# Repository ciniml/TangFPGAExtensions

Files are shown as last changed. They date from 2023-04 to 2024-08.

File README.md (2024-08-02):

# Extension boards for Tang series FPGA boards.

## 概要

Sipeedが製造・販売している、Tang Nano 9K, Tang Nano 20K およびTang Primer 20K向けのベースボードおよび拡張基板の設計データです。

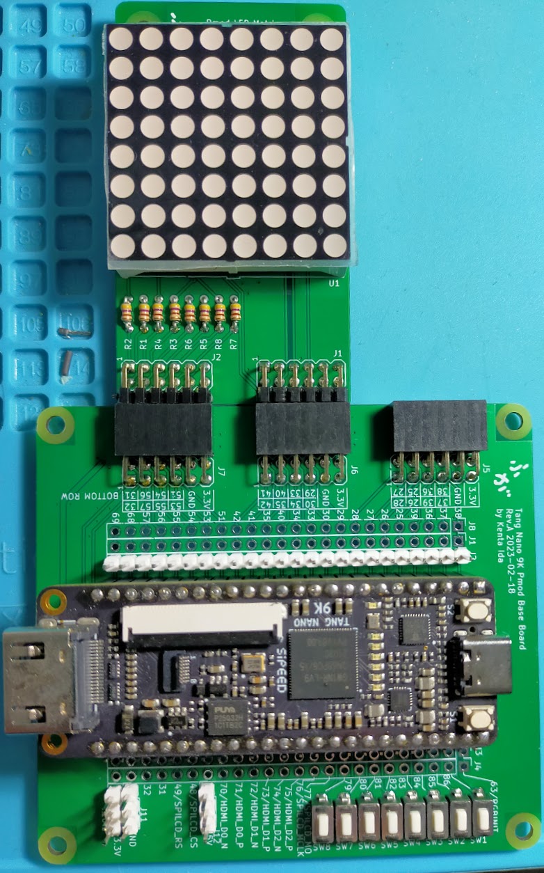
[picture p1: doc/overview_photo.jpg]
Tang Nano 9K + Matrix LED


## 内容

### 対象ボード

| 名前 | 略称  | 説明 | 購入先ページ |
| :--- | :---- | :--- | :--- |
| Tang Nano 9K | TN9K  | GW1NR-LV9搭載のボード。 | [秋月電子](https://akizukidenshi.com/catalog/g/gM-17448/) |
| Tang Primer 20K | TN20K | GW2A-LV18PG256 | [秋月電子](https://akizukidenshi.com/catalog/g/gM-17540/) |

### 基板一覧

| 名前 | 対象ボード | 説明 | KiCadプロジェクト | リビジョン |
| :--- | :--- | :--- | :--- | --- |
| [Tang Nano 9K Pmod Base Board](./README_TangNano_PmodBase.md) | TN9K | Tang Nano 9K用のPmod接続用ベースボード | [TangNano_PmodBase.kicad_pro](./TangNano_PmodBase.kicad_pro) | Rev. B |
| [Tang Primer 20K Pmod Extender ](./README_TangPrimer_PmodExtender.md) | TP20K | Tang Primer 20K用のPmod接続用拡張基板 | [TangPrimer_PmodExtender.kicad_pro](./TangPrimer_PmodExtender.kicad_pro) | Rev. B |
| [Pmod Debug Board](./README_Pmod_Debug.md) | TN9K,TP20K | Pmodのデバッグ用中継基板 | [Pmod_Debug.kicad_pro](./Pmod_Debug.kicad_pro) | Rev. A |
| Pmod HUB75 Connector Board | TN9K,TP20K | HUB75 LED Matrix接続用Pmod基板 | [Pmod_HUB75.kicad_pro](./Pmod_HUB75.kicad_pro) | Rev. A |
| Pmod LED Board | TN9K,TP20K | Pmodのデバッグ用LED基板 | [Pmod_LED.kicad_pro](./Pmod_LED.kicad_pro) | Rev. A |
| [Pmod Matrix LED](./README_Pmod_MatrixLED.md) | TN9K,TP20K | 8x8単色LEDマトリクスPmod基板 | [Pmod_MatrixLED.kicad_pro](./Pmod_MatrixLED.kicad_pro) | Rev. B |
| [Pmod MultiSegment (Single Port)](./README_Pmod_MultiSegment_SinglePort.md) | TN9K,TP20K | 6桁7+1セグメントLED Pmod基板 (シングルポート版) | [Pmod_MultiSegment_SinglePort.kicad_pro](./Pmod_MultiSegment_SinglePort.kicad_pro) | Rev. A |
| [Pmod Adapter Ethernet](./README_Pmod_Adapter_Ethernet.md) | TN9K,TP20K | LAN8720 Ethernet PHYボード用 Pmod アダプタ | [Pmod_Adapter_Ethernet.kicad_pro](./Pmod_Adapter_Ethernet.kicad_pro) | Rev. A |

## ライセンス

<br />この 作品 は <a rel="license" href="http://creativecommons.org/licenses/by/4.0/">クリエイティブ・コモンズ 表示 4.0 国際 ライセンス</a>の下に提供されています。

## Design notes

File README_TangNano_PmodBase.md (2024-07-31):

# Tang Nano 9K Pmod Base Board

## 概要

Tang Nano 9K用のPmod接続用ベースボード。Pmod 3ポート使用可能。 Pmodの信号線はすべて3.3V。 8個のタクトスイッチを実装可能 (すべて1.8V系ピン使用)

## 部品リスト

| リファレンス | 個数 | 値 | 購入元 | 備考 |
| :--- | ---- | --- | --- | --- |
| J1, J2, J3, J4, J8, J9, | 6 | 1x24 2.54mm ピンヘッダ or ピンソケット | ピンヘッダ [秋月電子](https://akizukidenshi.com/catalog/g/gC-00167/) <br/> ピンソケット [秋月電子](https://akizukidenshi.com/catalog/g/gC-05779/) | 使い方に応じてヘッダ・ソケット好きな方を実装 |
| J5, J6, J7, | 3 | 2x6 2.54mm ライトアングル ピンソケット | [秋月電子](https://akizukidenshi.com/catalog/g/gC-16795/) | |
| J10, J11, J12, | 3 | 1x3 2.54mm ピンヘッダ | ピンヘッダ [秋月電子](https://akizukidenshi.com/catalog/g/gC-00167/) | |
| R1, R2, R3, R4, R5, R6, R7, R8, | 8 | 1kΩ 1/6 | [秋月電子](https://akizukidenshi.com/catalog/g/gR-16102/) | |
| SW1, SW2, SW3, SW4, SW5, SW6, SW7, SW8, | 8 | TVBP06-B043CW-B タクトスイッチ | [秋月電子](https://akizukidenshi.com/catalog/g/gP-08074/) | |
| U1, | 2 | TangNano9K接続用ピンソケット 1x24 2.54mm ピンソケット | ピンソケット [秋月電子](https://akizukidenshi.com/catalog/g/gC-05779/) <br/> 細ピンソケット [秋月電子](https://akizukidenshi.com/catalog/g/gC-10073/) | 細にしておくとブレッドボードと共用しやすい |
| | 2 | TangNano9K接続用ピンヘッダ 1x24 2.54mm ピンヘッダ | ピンヘッダ [秋月電子](https://akizukidenshi.com/catalog/g/gC-00167/) <br/> 細ピンヘッダ [秋月電子](https://akizukidenshi.com/catalog/g/gC-06631/) | 細にしておくとブレッドボードと共用しやすい |

### 秋月買い物リスト用

秋月で部品をそろえる場合のリスト。Tang Nano 9Kに細ピンヘッダを使用、信号引き出しのピンは、ピンソケット 1列、ピンヘッダ 2列の構成

| リファレンス | 個数 | セット数 | 値 | 秋月番号 |
| :--- | ---: | ---: | --- | ---: |
| J1, J2, J3, J4, J8, J9, | 6 | 6 | 1x24 2.54mm ピンヘッダ | 100167 |
| J10, J11, J12, | 3 | 1 | 1x3 2.54mm ピンヘッダ | 100167 |
| J2, J9, | 2 | 2 | 1x24 2.54mm ピンソケット | 105779 |
| J5, J6, J7, | 3 | 3 | 2x6 2.54mm ライトアングル ピンソケット | 116795 |
| R1, R2, R3, R4, R5, R6, R7, R8, | 8 | 1 | 1kΩ 1/6 | 116102 |
| SW1, SW2, SW3, SW4, SW5, SW6, SW7, SW8, | 8 | 8 | TVBP06-B043CW-B タクトスイッチ | 108074 |
| U1, | 2 | 2 | 1x24 2.54mm 細ピンソケット | 110073 |
| | 2 | 2 | 1x24 2.54mm 細ピンヘッダ | 106631 |
| | 1 | 1 | Tang Nano 9K | 117448 |

## 回路図

回路図 (SVG)
[回路図 (PDF)](./doc/TangNano_PmodBase_Schematic.pdf)

## 外観

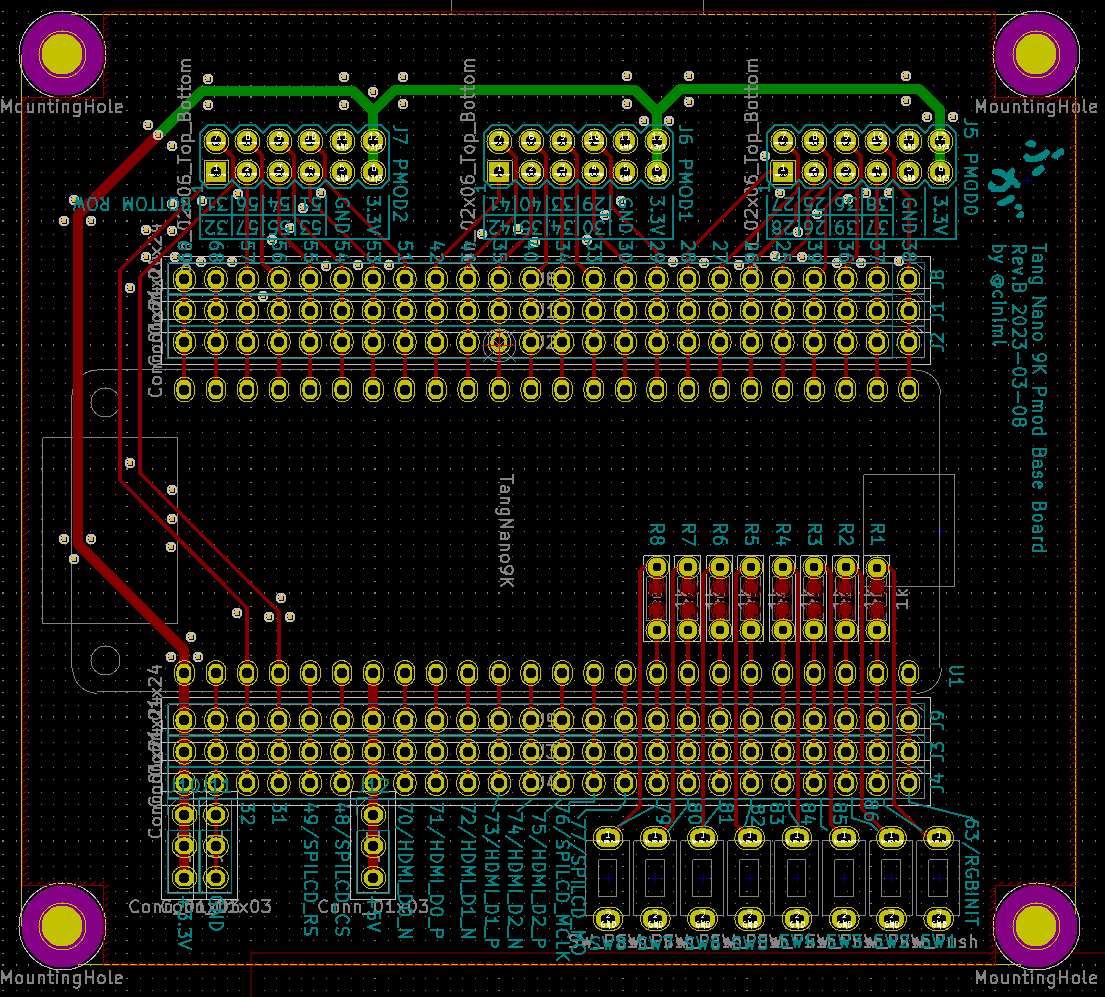
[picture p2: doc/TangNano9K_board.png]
ボード画像1


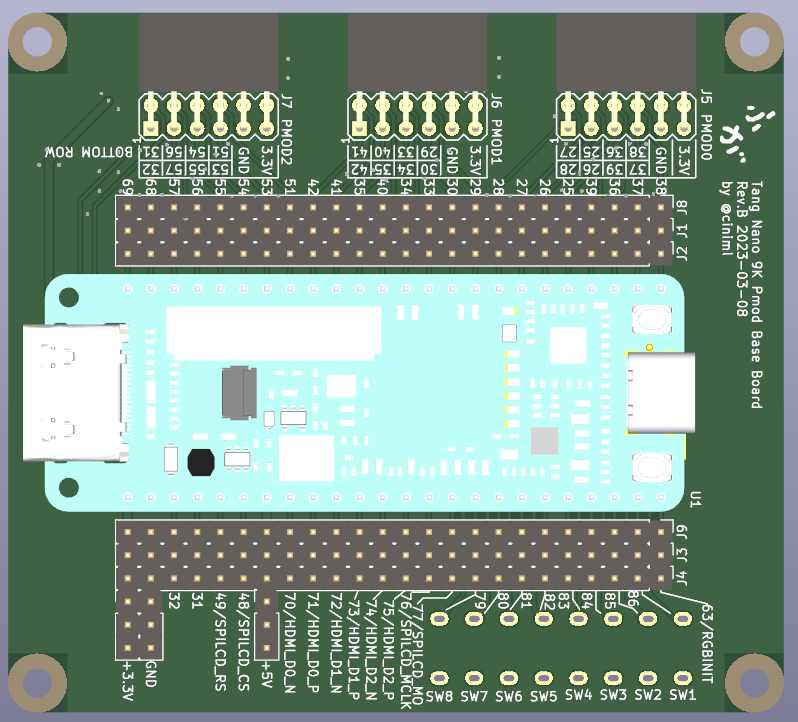
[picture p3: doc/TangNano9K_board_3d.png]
ボード画像2


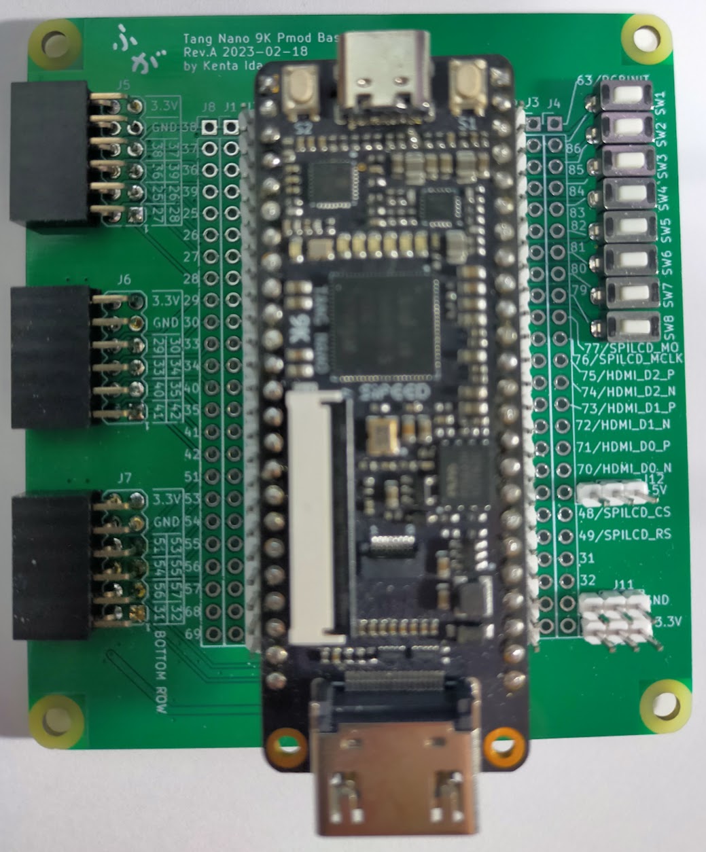
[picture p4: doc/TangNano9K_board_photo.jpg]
ボード写真


## サンプルプロジェクト

[Tang Nano 9K向けサンプル](https://github.com/ciniml/fpga_samples/tree/main/eda/cpu_matrix_led/src/tangnano9k_pmod)

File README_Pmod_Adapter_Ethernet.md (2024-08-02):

# Ethernet Pmod Adapter

## 概要

Waveshareやその他の互換ボードメーカーが販売しているMicrochip LAN8720を使ったEthernet PHYボードをPmodポートに接続するためのアダプタです。

* WaveshareのLAN8720ボード https://www.waveshare.com/lan8720-eth-board.htm
* Amazonで買える互換品 (不良品率高いので注意) https://www.amazon.co.jp/KKHMF-%E9%AB%98%E6%80%A7%E8%83%BDLAN8720%E3%82%A4%E3%83%BC%E3%82%B5%E3%83%8D%E3%83%83%E3%83%88%E3%83%9C%E3%83%BC%E3%83%8910-100%E3%82%A4%E3%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

## 部品リスト

| リファレンス | 個数 | 値 | 購入元 | 備考 |
| :--- | ---- | --- | --- | --- |
| J1 | 1 | 2x6 2.54 ライトアングル ピンヘッダ | [秋月電子](https://akizukidenshi.com/catalog/g/g116794/) | |
| J2 | 1 | 2x7 2.54mm ライトアングル ピンソケット | 2x10 ピンソケット [秋月電子](https://akizukidenshi.com/catalog/g/g105755/) | 2x7に折って使う |

### 秋月買い物リスト用

秋月で部品をそろえる場合のリスト。

| リファレンス | 個数 | セット数 | 値 | 秋月番号 |
| :--- | ---: | ---: | --- | ---: |
| J1 | 1 | 1 | ピンヘッダー L型 2×6 (12P) | 116794 |
| J2 | 3 | 1 | L型ピンソケット 2×10(20P)  | 105755 |

## 回路図

回路図 (SVG)
[回路図 (PDF)](./doc/Pmod_Adapter_Ethernet.pdf)

## 外観

ボード画像

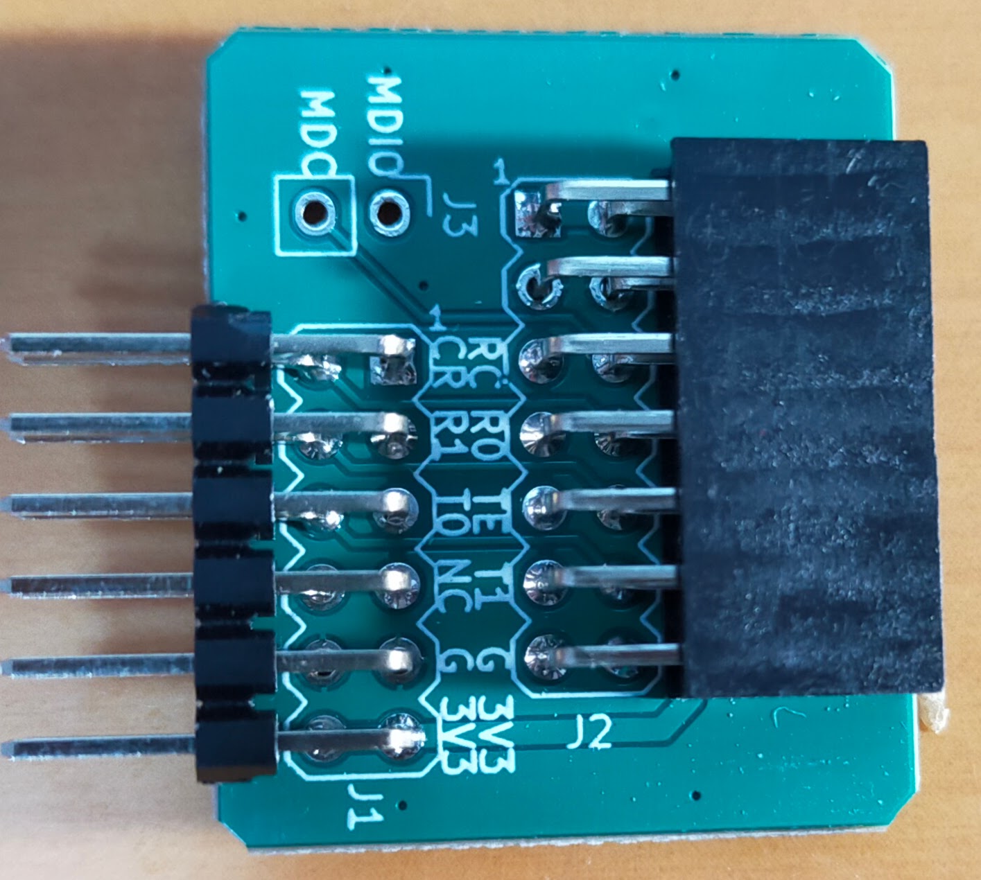
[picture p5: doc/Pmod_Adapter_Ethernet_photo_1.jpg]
ボード写真1 (単体)

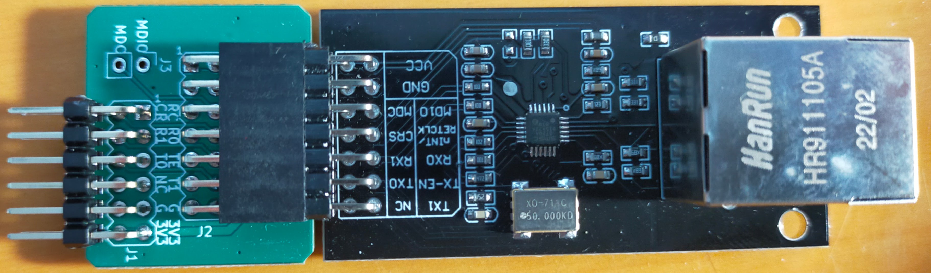
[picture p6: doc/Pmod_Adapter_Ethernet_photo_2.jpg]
ボード写真2 (LAN8720ボード接続)


## サンプルプロジェクト

[Tang Nano 9K向けサンプル](https://github.com/ciniml/fpga_samples/tree/main/eda/ethernet_icmp/src/tangnano9k_pmod)

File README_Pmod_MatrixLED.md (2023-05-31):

# Pmod Matrix LED

## 概要

秋月電子で購入可能なOptosupplyの8x8マトリクスLED OSL641501-AXA のPmodモジュールです。Pmod 2ポート使用。

## 部品リスト

| リファレンス | 個数 | 値 | 購入元 | 備考 |
| :--- | ---- | --- | --- | --- |
| J1, J2, | 2 | 2x6 2.54mm ライトアングル ピンヘッダ | [秋月電子](https://akizukidenshi.com/catalog/g/gC-00148/) | 2x6で分割する |
| R1, R2, R3, R4, R5, R6, R7, R8, | 8 | 470Ω 1/6W | [秋月電子](https://akizukidenshi.com/catalog/g/gR-16471/) | |
| U1, | 1 | OSL641501-ARA | [秋月電子](OSL641501-AXA) | |

## 回路図

回路図 (SVG)
[回路図 (PDF)](./doc/Pmod_MatrixLED_Schematic.pdf)

## 外観

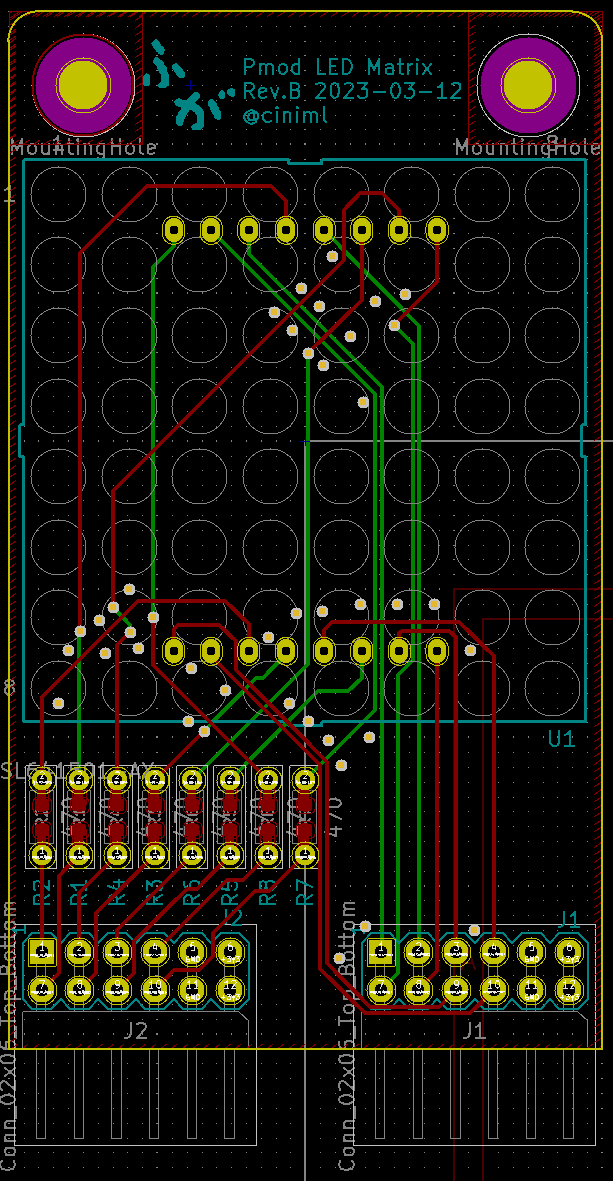
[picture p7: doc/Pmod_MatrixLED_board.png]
ボード画像1


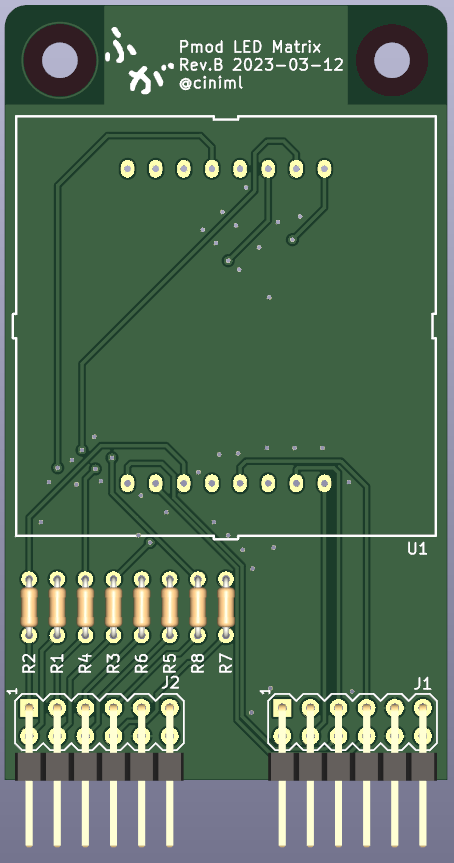
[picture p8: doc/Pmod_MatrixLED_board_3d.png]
ボード画像2


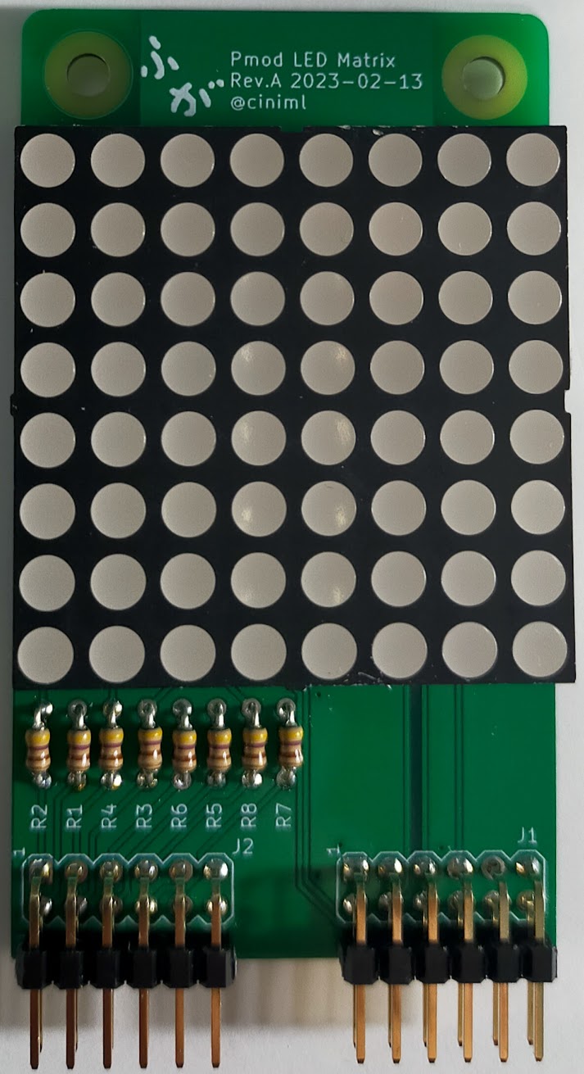
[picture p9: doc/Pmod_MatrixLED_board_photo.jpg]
ボード写真


## サンプルプロジェクト

[Tang Nano 9K向けサンプル](https://github.com/ciniml/fpga_samples/tree/main/eda/cpu_matrix_led/src/tangnano9k_pmod)

[Tang Primer 20K向けサンプル](https://github.com/ciniml/fpga_samples/tree/main/eda/cpu_matrix_led/src/tangnano9k_pmod)

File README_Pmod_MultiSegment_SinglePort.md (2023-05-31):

# Pmod MultieSegment (Single Port版)

## 概要

秋月電子で購入可能なOptosupplyの6桁 7+1セグメントLED [OSL60362-LR](https://akizukidenshi.com/catalog/g/gI-17987/) のPmodモジュールです。
単純に接続した場合は2ポート必要になりますが、8bitシフトレジスタを使って桁選択とセグメント出力をそれぞれ4線で制御し、Pmod 1ポートに収めています。
FPGA側の制御回路は少し複雑になりますが、Pmodポートを他につかうことができます。

## 部品リスト

| リファレンス | 個数 | 値 | 購入元 | 備考 |
| :--- | ---- | --- | --- | --- |
| J1, | 1 | 2x6 2.54mm ライトアングル ピンヘッダ | [秋月電子](https://akizukidenshi.com/catalog/g/gC-00148/) | 2x6で分割する |
| R1, R2, R3, R4, R5, R6, | 6 | 470Ω 1/6W | [秋月電子](https://akizukidenshi.com/catalog/g/gR-16471/) | |
| U2, | 1 | OSL60362-LX | [秋月電子](https://akizukidenshi.com/catalog/g/gI-17987/) | カソードコモンタイプを使う | |
| U1, U3 | 2 | TC74HC595AF | [秋月電子](https://akizukidenshi.com/catalog/g/gI-10077/) |  | |

## 回路図

回路図 (SVG)
[回路図 (PDF)](./doc/Pmod_MultiSegment_SinglePort.pdf)

## 外観

準備中

## サンプルプロジェクト

準備中

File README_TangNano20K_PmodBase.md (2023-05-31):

# Tang Nano 20K Pmod Base Board

## 概要

Tang Nano 20K用のPmod接続用ベースボード。Pmod 3ポート使用可能。 Pmodの信号線はすべて3.3V。 8個のタクトスイッチを実装可能

## 部品リスト

| リファレンス | 個数 | 値 | 購入元 | 備考 |
| :--- | ---- | --- | --- | --- |
| J1, J2, J3, J4, J8, J9, | 6 | 1x24 2.54mm ピンヘッダ or ピンソケット | ピンヘッダ [秋月電子](https://akizukidenshi.com/catalog/g/gC-00167/) <br/> ピンソケット [秋月電子](https://akizukidenshi.com/catalog/g/gC-05779/) | 使い方に応じてヘッダ・ソケット好きな方を実装 |
| J5, J6, J7, | 3 | 2x6 2.54mm ライトアングル ピンソケット | [秋月電子](https://akizukidenshi.com/catalog/g/gC-16795/) | |
| J10, J11, J12, | 3 | 1x3 2.54mm ピンヘッダ | ピンヘッダ [秋月電子](https://akizukidenshi.com/catalog/g/gC-00167/) | |
| R1, R2, R3, R4, R5, R6, R7, R8, | 8 | 1kΩ 1/6 | [秋月電子](https://akizukidenshi.com/catalog/g/gR-16102/) | |
| SW1, SW2, SW3, SW4, SW5, SW6, SW7, SW8, | 8 | TVBP06-B043CW-B タクトスイッチ | [秋月電子](https://akizukidenshi.com/catalog/g/gP-08074/) | |
| U1, | 2 | TangNano9K接続用ピンソケット 1x20 2.54mm ピンソケット | ピンソケット [秋月電子](https://akizukidenshi.com/catalog/g/gC-05779/) <br/> 細ピンソケット [秋月電子](https://akizukidenshi.com/catalog/g/gC-10073/) | 細にしておくとブレッドボードと共用しやすい |
| | 2 | TangNano9K接続用ピンヘッダ 1x20 2.54mm ピンヘッダ | ピンヘッダ [秋月電子](https://akizukidenshi.com/catalog/g/gC-00167/) <br/> 細ピンヘッダ [秋月電子](https://akizukidenshi.com/catalog/g/gC-06631/) | 細にしておくとブレッドボードと共用しやすい |

## 回路図

回路図 (SVG)
[回路図 (PDF)](./doc/TangNano20K_PmodBase_Schematic.pdf)

## 外観

基板レイアウト(表)
基板レイアウト(裏)

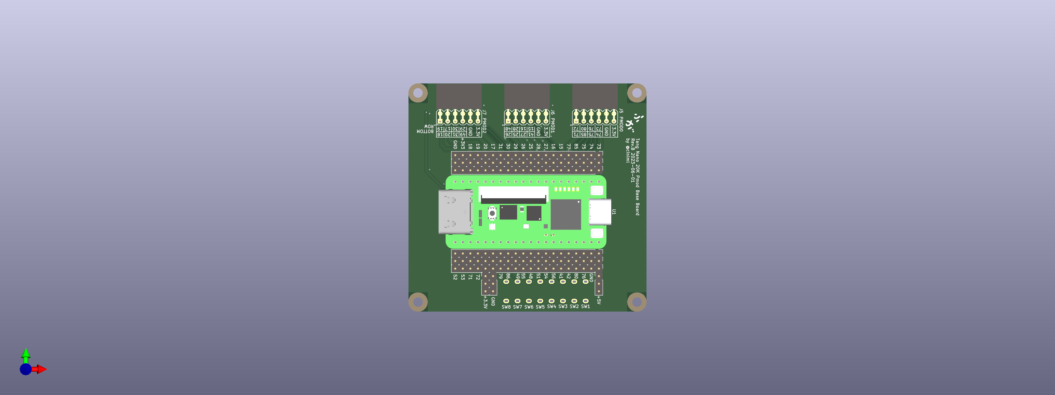
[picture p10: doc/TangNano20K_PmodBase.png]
ボード画像


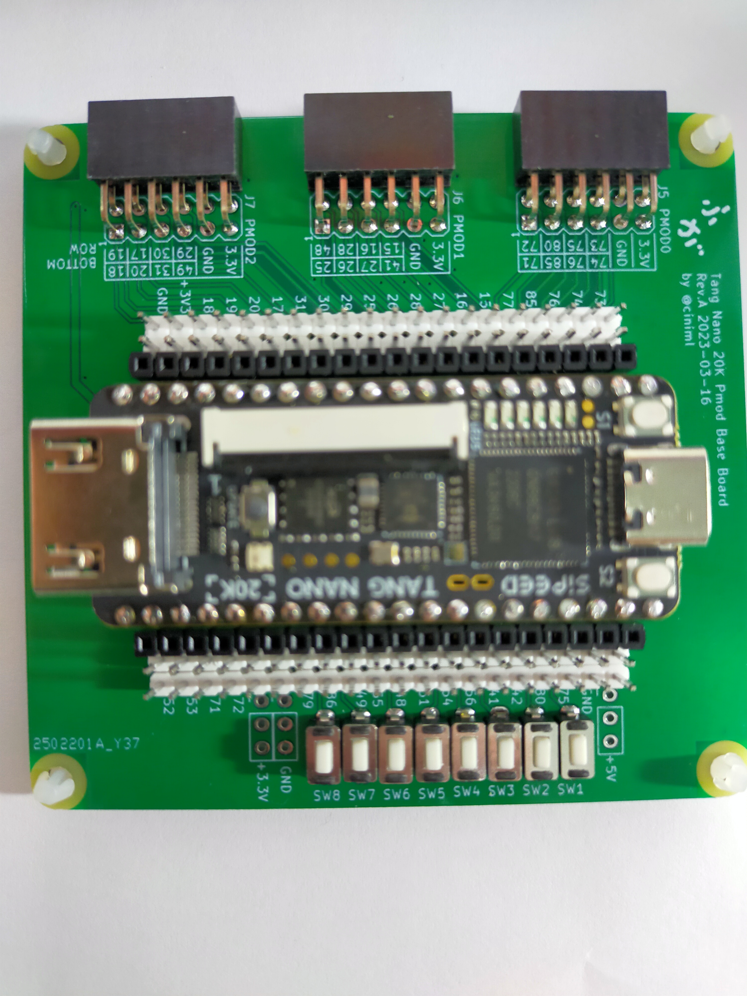
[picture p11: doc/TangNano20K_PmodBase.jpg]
ボード写真


## サンプルプロジェクト

[Tang Nano 20K向けサンプル](https://github.com/ciniml/fpga_samples/tree/main/eda/cpu_matrix_led/src/tangnano20k)

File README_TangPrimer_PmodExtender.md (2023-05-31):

# Tang Primer 20K Pmod Extender

## 概要

Tang Primer 20K用のPmod接続用拡張ボード。

Tang Primer 20KにはもともとPmod相当のポートが4つついているが、Pmod規格が定める形状の制約を満たしておらず、Pmod規格ボードを接続することが難しい。
Tang Primer 20K Pmod ExtenderはTang Primer 20KのPmod相当ポート4つに接続し、各ポートをPmod規格が定める向きおよび配置に変換します。

## 部品リスト

| リファレンス | 個数 | 値 | 購入元 | 備考 |
| :--- | ---- | --- | --- | ---- |
| J1, J2, J3, J4, | 4 | 2x6 2.54mm ピンヘッダ | ピンヘッダ [秋月電子](https://akizukidenshi.com/catalog/g/gC-00167/) | |
| J5, J6, J7, J8, | 4 | 2x6 2.54mm ライトアングル ピンソケット | [秋月電子](https://akizukidenshi.com/catalog/g/gC-16795/) | |

## 回路図

回路図 (SVG)
[回路図 (PDF)](./doc/TangPrimer_PmodExtender_Schematic.pdf)

## 外観

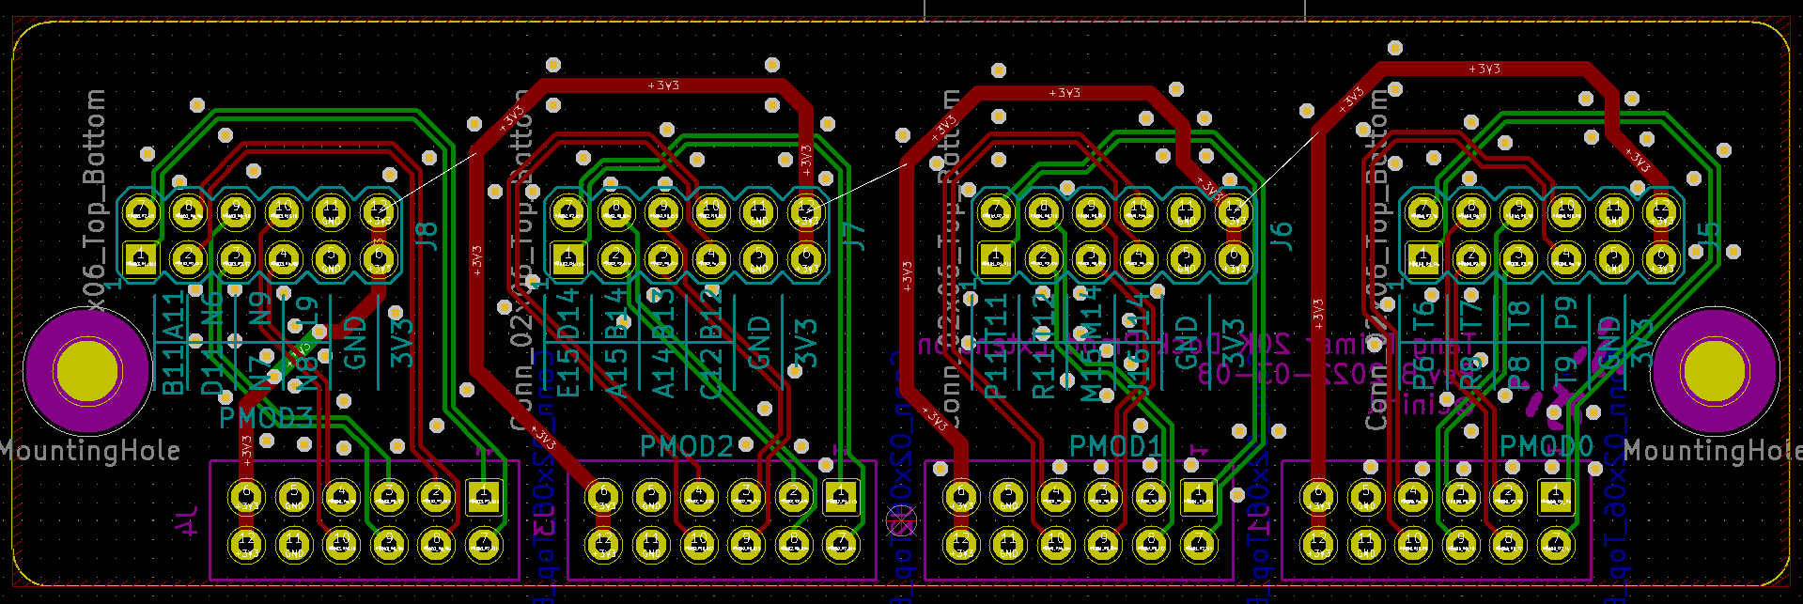
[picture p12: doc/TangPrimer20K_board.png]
ボード画像1


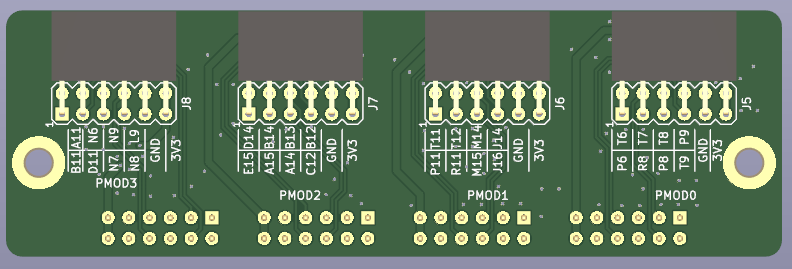
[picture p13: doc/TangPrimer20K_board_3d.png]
ボード画像2


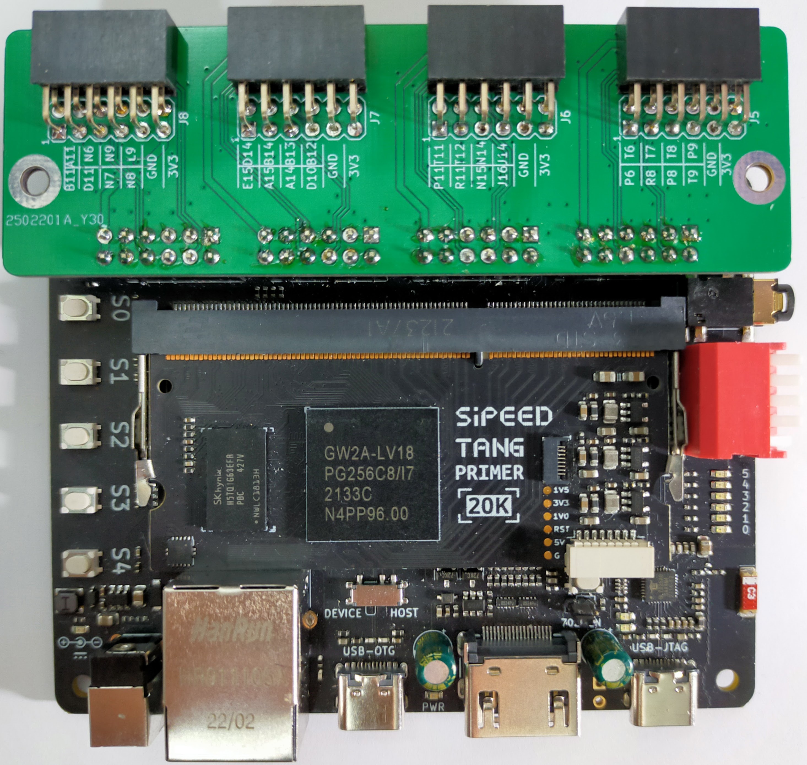
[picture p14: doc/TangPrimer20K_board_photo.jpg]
ボード写真


## サンプルプロジェクト

[Tang Primer 20K向けサンプル](https://github.com/ciniml/fpga_samples/tree/main/eda/cpu_matrix_led/src/tangprimer20k)

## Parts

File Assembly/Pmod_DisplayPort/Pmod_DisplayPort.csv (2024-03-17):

Designator | Comment | Footprint | MPN | JLCPCB Part #
C1 | 100n | Capacitor_SMD:C_0402_1005Metric | CL05B104KB54PNC | C307331
C2 | 100n | Capacitor_SMD:C_0402_1005Metric | CL05B104KB54PNC | C307331
C3 | 100n | Capacitor_SMD:C_0402_1005Metric | CL05B104KB54PNC | C307331
C4 | 100n | Capacitor_SMD:C_0402_1005Metric | CL05B104KB54PNC | C307331
C5 | 100n | Capacitor_SMD:C_0402_1005Metric | CL05B104KB54PNC | C307331
C6 | 100n | Capacitor_SMD:C_0402_1005Metric | CL05B104KB54PNC | C307331
C7 | 100n | Capacitor_SMD:C_0402_1005Metric | CL05B104KB54PNC | C307331
C8 | 100n | Capacitor_SMD:C_0402_1005Metric | CL05B104KB54PNC | C307331
C9 | 100n | Capacitor_SMD:C_0402_1005Metric | CL05B104KB54PNC | C307331
C10 | 100n | Capacitor_SMD:C_0402_1005Metric | CL05B104KB54PNC | C307331
CN1 | HYC16-DP20-178 | local:DisplayPort_HOAUC-HYC16-DP20-178 | HYC16-DP20-178 | C711350
R1 | 100k | Resistor_SMD:R_0402_1005Metric | 0402WGF1003TCE | C25741
R2 | 100k | Resistor_SMD:R_0402_1005Metric | 0402WGF1003TCE | C25741
R3 | 49.9 | Resistor_SMD:R_0402_1005Metric | 0402WGF499JTCE | C25120
R4 | 49.9 | Resistor_SMD:R_0402_1005Metric | 0402WGF499JTCE | C25120
R5 | 49.9 | Resistor_SMD:R_0402_1005Metric | 0402WGF499JTCE | C25120
R6 | 49.9 | Resistor_SMD:R_0402_1005Metric | 0402WGF499JTCE | C25120
R7 | 49.9 | Resistor_SMD:R_0402_1005Metric | 0402WGF499JTCE | C25120
R8 | 49.9 | Resistor_SMD:R_0402_1005Metric | 0402WGF499JTCE | C25120
R9 | 49.9 | Resistor_SMD:R_0402_1005Metric | 0402WGF499JTCE | C25120
R10 | 49.9 | Resistor_SMD:R_0402_1005Metric | 0402WGF499JTCE | C25120
R11 | 49.9 | Resistor_SMD:R_0402_1005Metric | 0402WGF499JTCE | C25120
R12 | 49.9 | Resistor_SMD:R_0402_1005Metric | 0402WGF499JTCE | C25120
R13 | 100k | Resistor_SMD:R_0402_1005Metric | 0402WGF1003TCE | C25741
R14 | 10k | Resistor_SMD:R_0402_1005Metric | 0402WGF1002TCE | C25744

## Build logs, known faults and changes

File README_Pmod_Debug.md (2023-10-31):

# Pmod Debug 中継基板

## 概要

PmodモジュールとPmod対応ボードの間に挿入して、Pmodの信号線をロジック・アナライザ等で観測しやすくするための中継基板です。

## 部品リスト

| リファレンス | 個数 | 値 | 購入元 | 備考 |
| :--- | ---- | --- | --- | --- |
| J1, | 1 | 2x6 2.54mm ライトアングル ピンヘッダ | [秋月電子](https://akizukidenshi.com/catalog/g/gC-00148/) | 2x6で分割する |
| J2, | 1 | 2x6 2.54mm ピンヘッダ | [秋月電子](https://akizukidenshi.com/catalog/g/gC-00167/) | 2x6で分割する |
| J3, | 1 | 2x6 2.54mm ライトアングル ピンソケット | [秋月電子](https://akizukidenshi.com/catalog/g/gC-16795/) | 2x6で分割する |

## 回路図

回路図 (SVG)
[回路図 (PDF)](./doc/Pmod_Debug.pdf)

## 外観

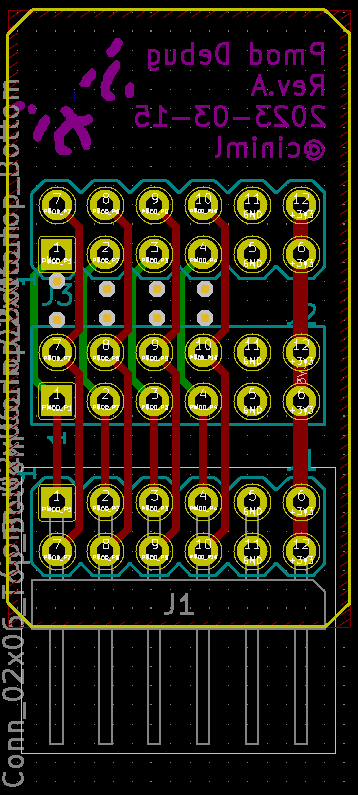
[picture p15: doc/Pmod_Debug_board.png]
ボード画像1


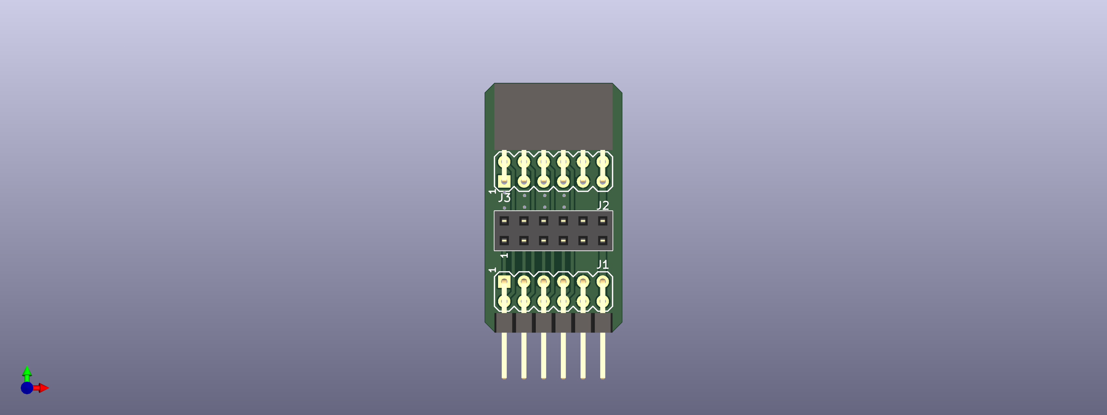
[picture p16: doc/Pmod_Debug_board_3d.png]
ボード画像2


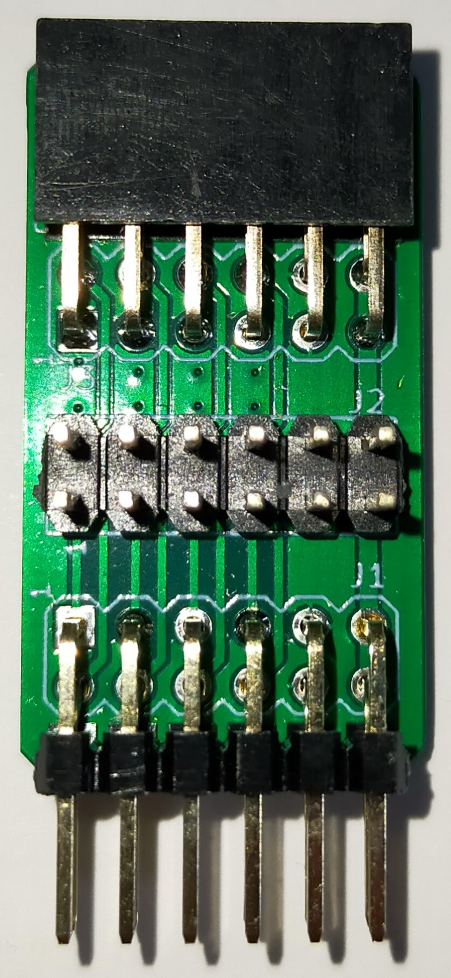
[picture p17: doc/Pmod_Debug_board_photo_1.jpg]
ボード写真1


ボード写真2

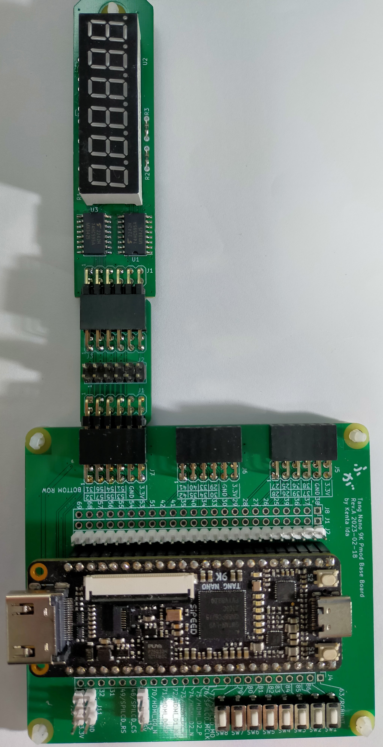
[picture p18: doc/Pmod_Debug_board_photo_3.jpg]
ボード写真3


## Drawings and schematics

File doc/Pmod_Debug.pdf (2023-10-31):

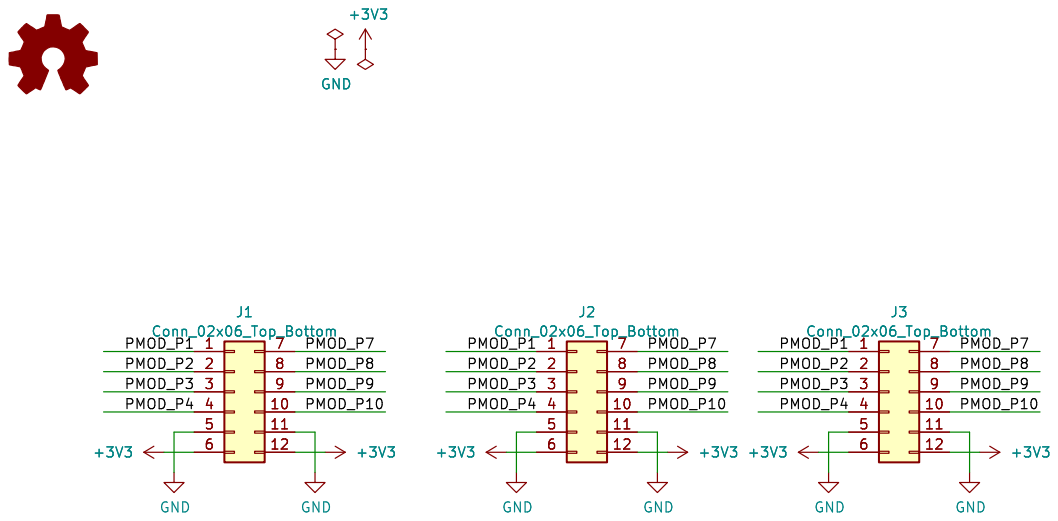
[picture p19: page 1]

Id: 1/1 Title: Pmod Matrix LED module

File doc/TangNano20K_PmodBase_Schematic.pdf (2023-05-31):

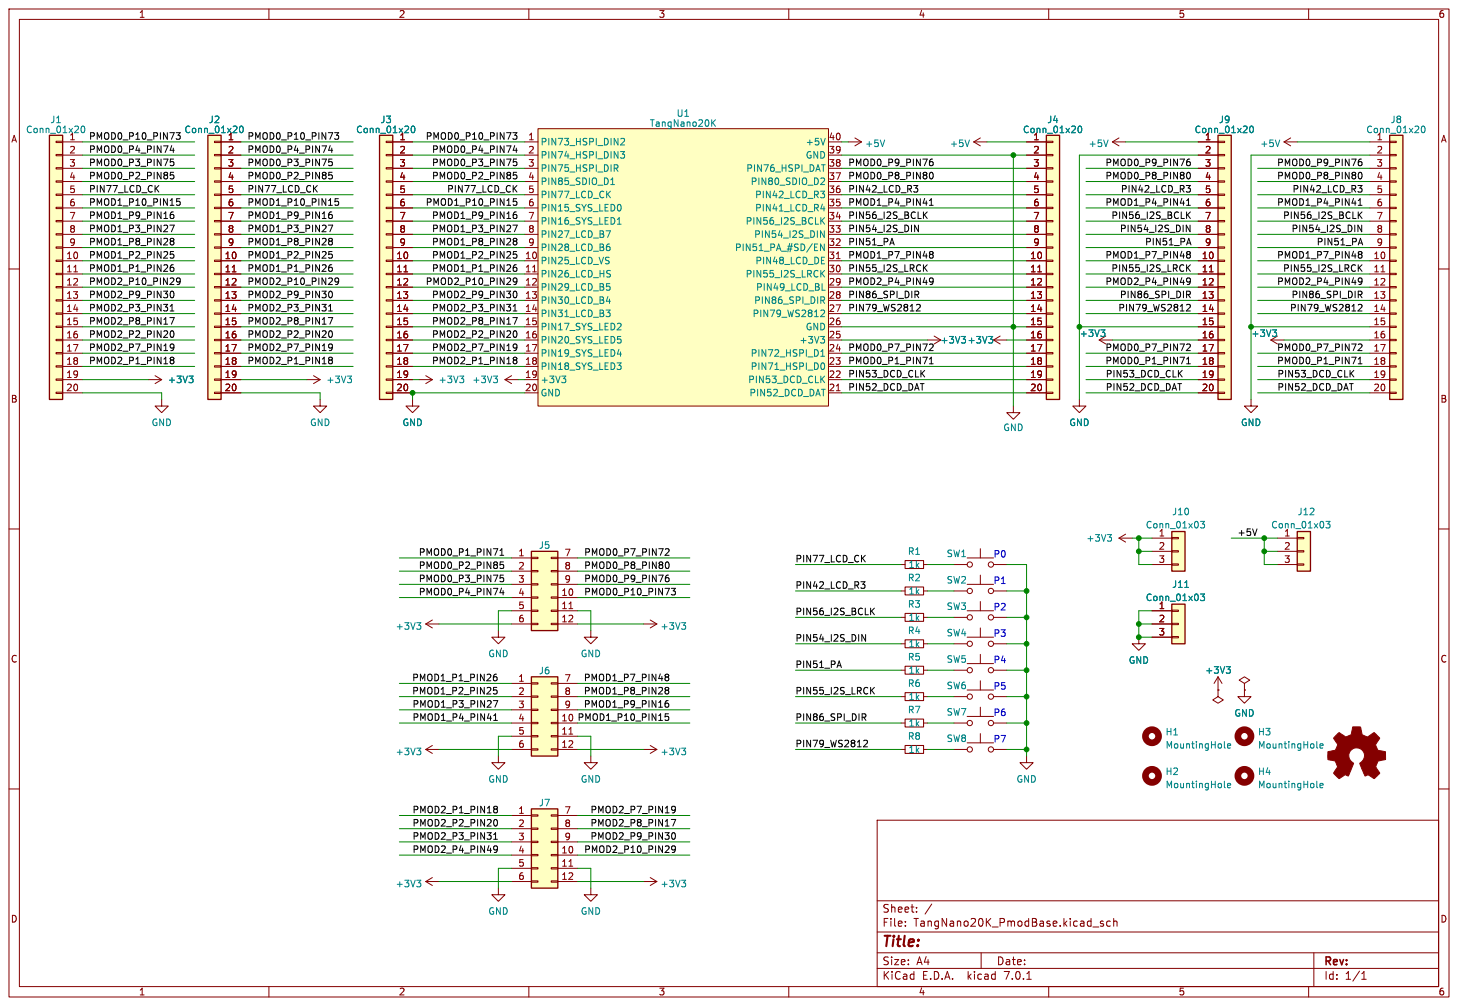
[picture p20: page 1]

Id: 1/1 Title: File: TangNano20K_PmodBase.kicad_sch Sheet: /

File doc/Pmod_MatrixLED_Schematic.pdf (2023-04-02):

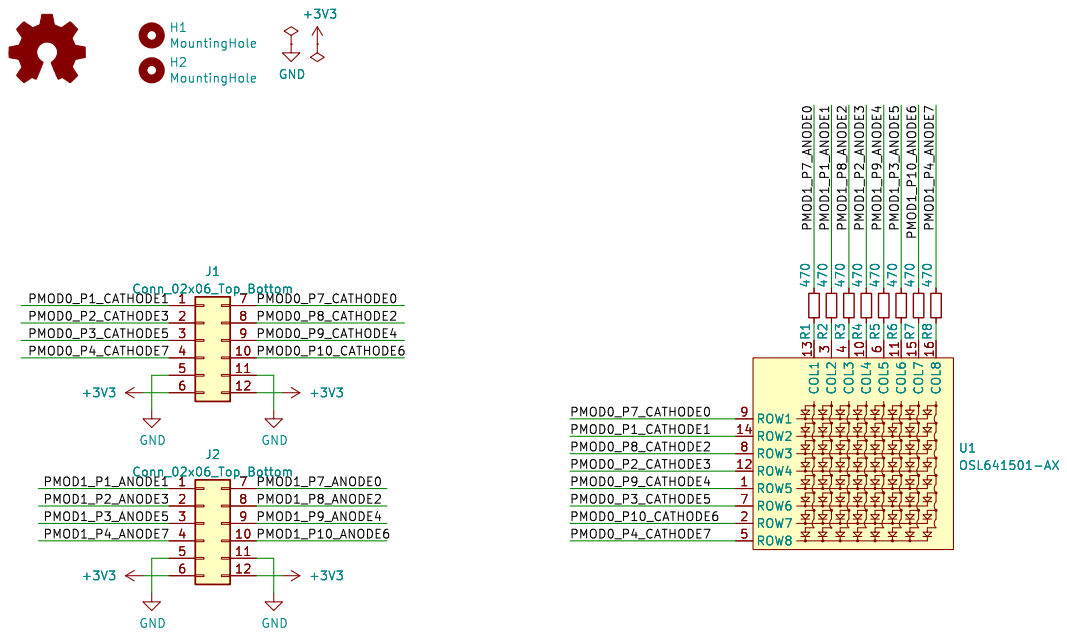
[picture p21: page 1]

Id: 1/1 Title: Pmod Matrix LED module

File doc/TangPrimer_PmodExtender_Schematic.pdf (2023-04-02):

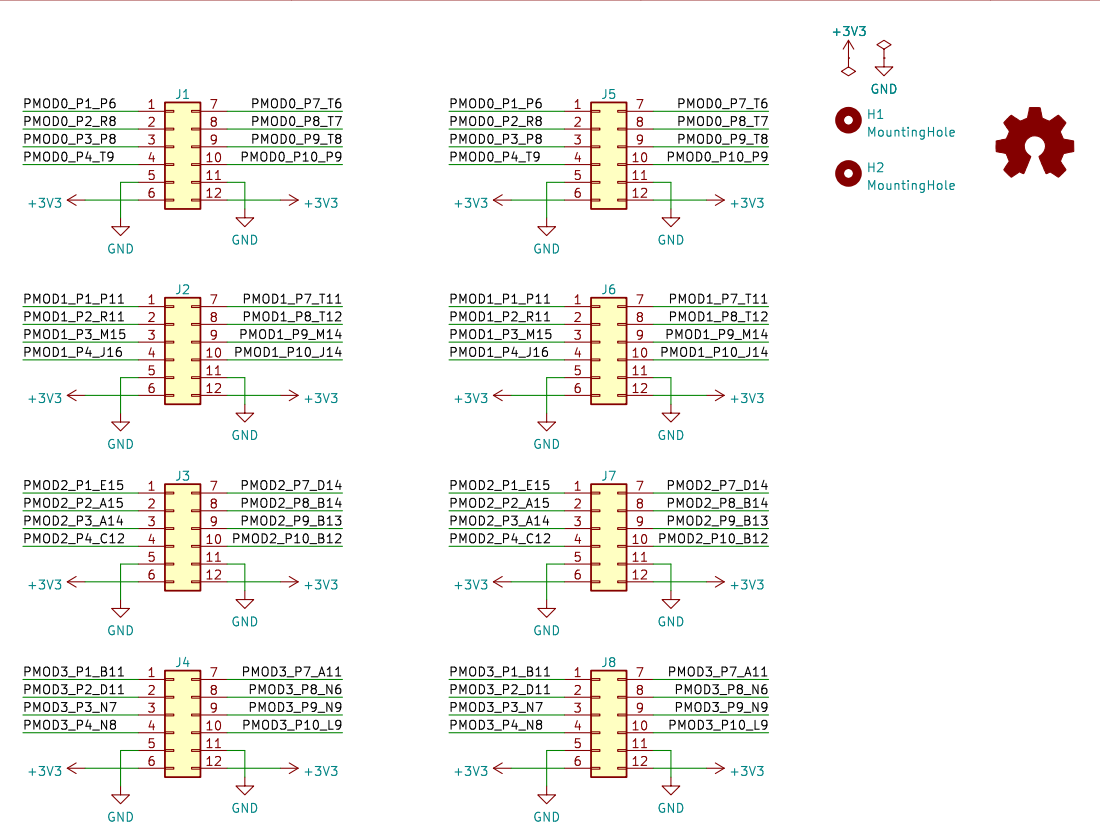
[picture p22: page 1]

Id: 1/1 Title: Tang Primer 20K Pmod Extender File: TangPrimer_PmodExtender.kicad_sch Sheet: /

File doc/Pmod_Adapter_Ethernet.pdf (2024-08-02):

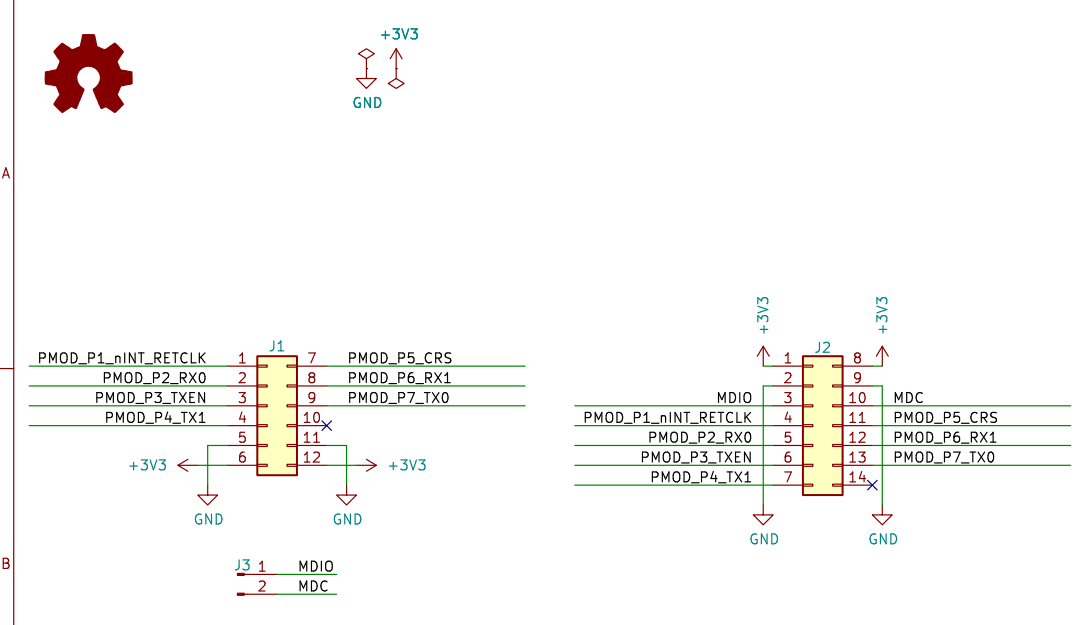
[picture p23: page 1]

Id: 1/1 Title: Pmod Matrix LED module

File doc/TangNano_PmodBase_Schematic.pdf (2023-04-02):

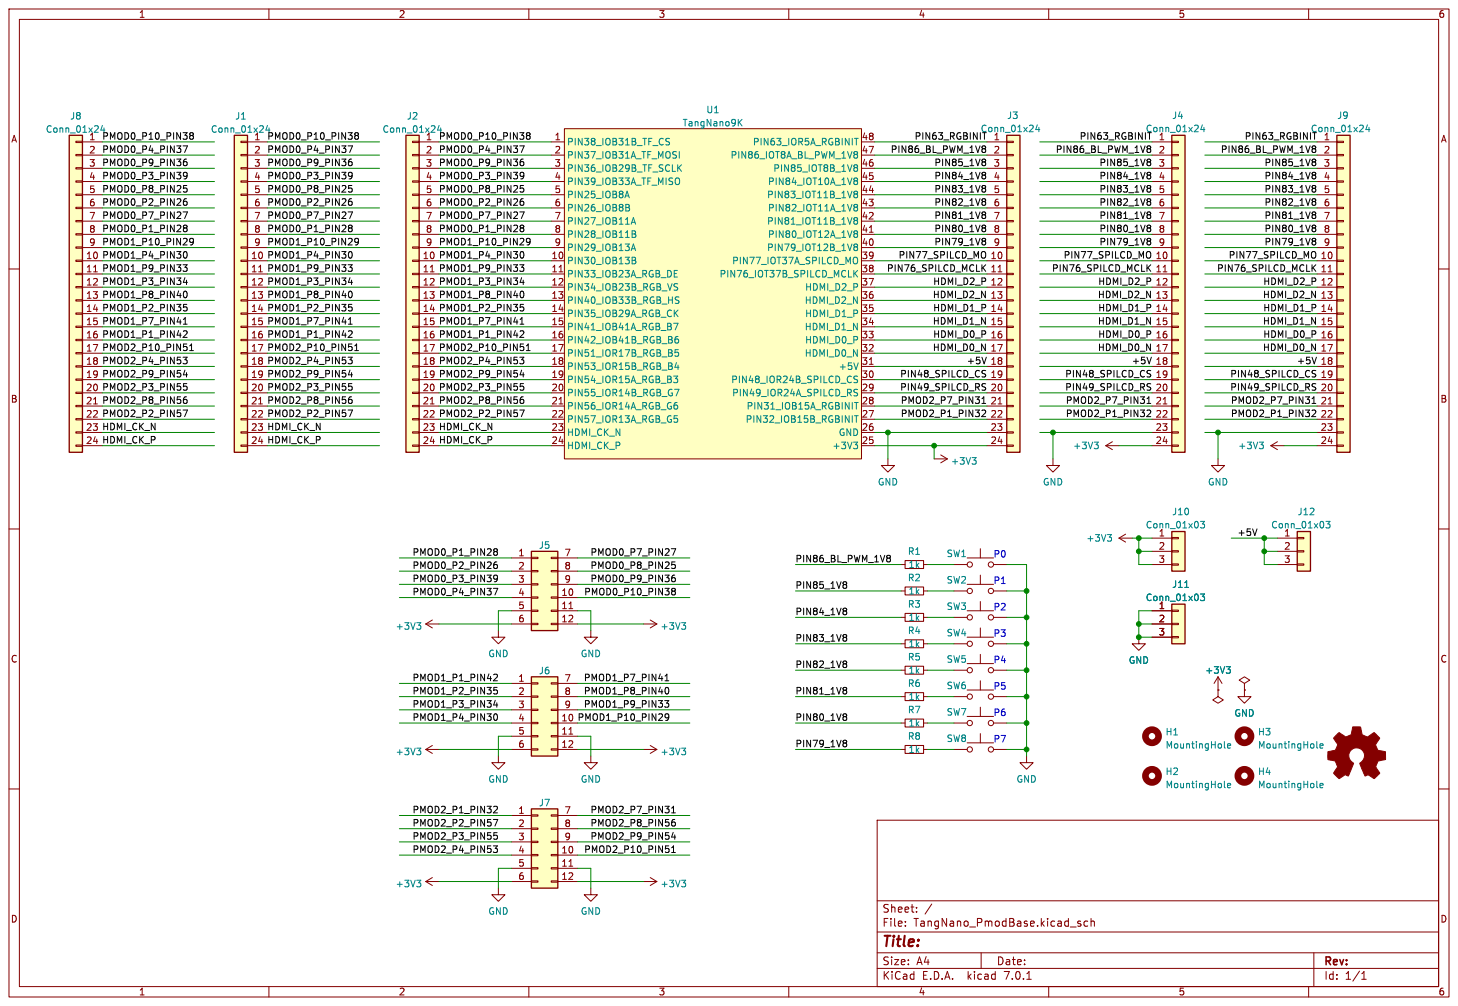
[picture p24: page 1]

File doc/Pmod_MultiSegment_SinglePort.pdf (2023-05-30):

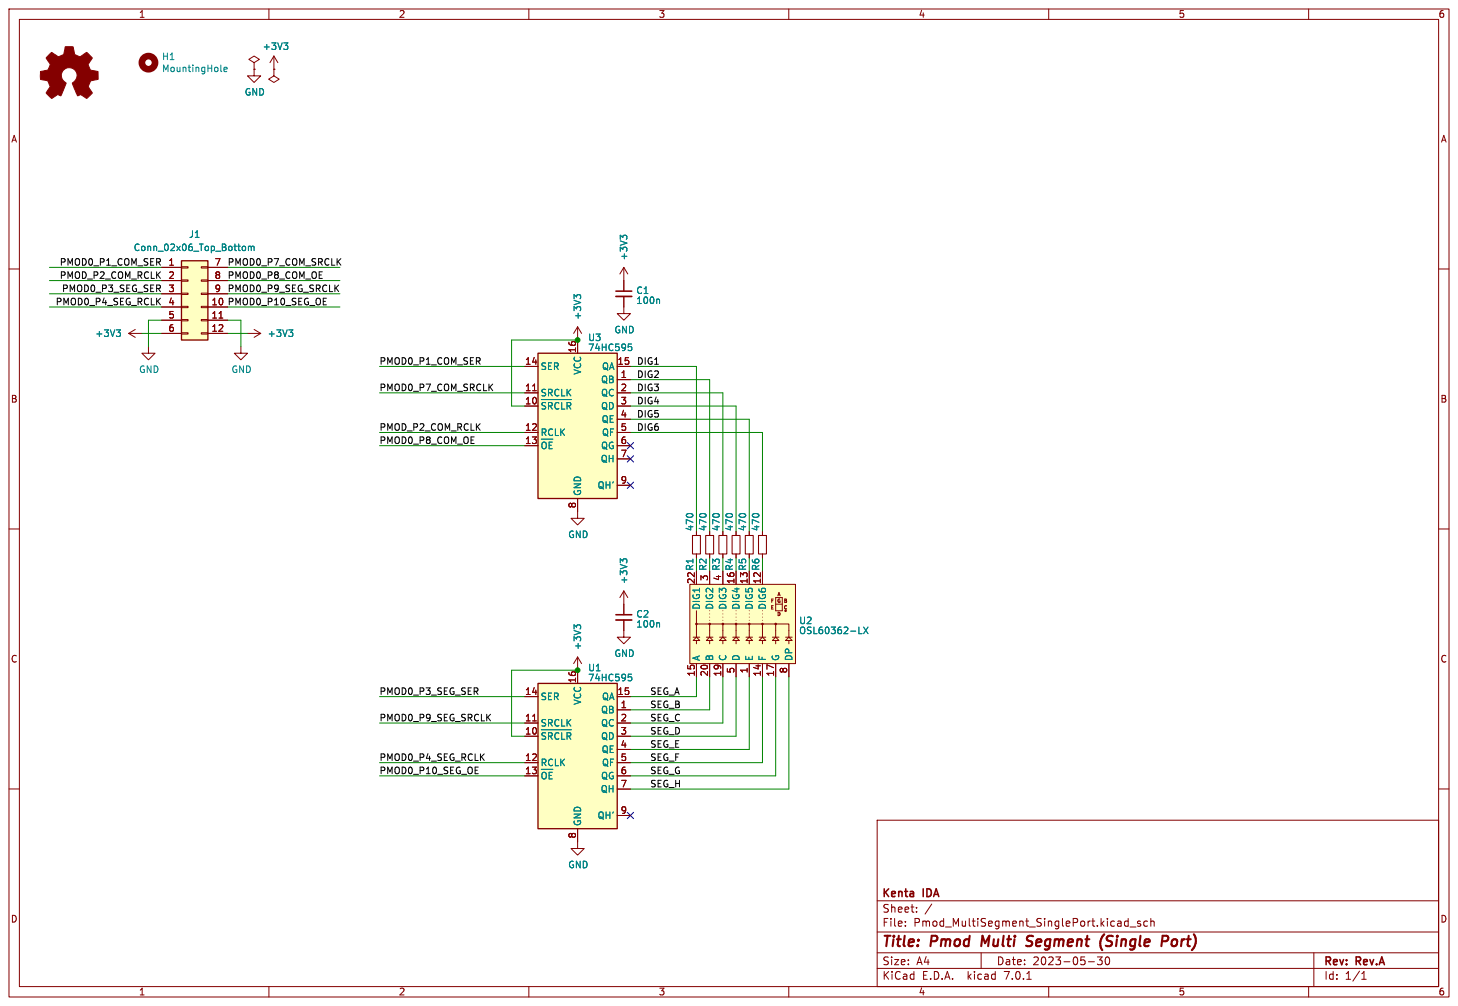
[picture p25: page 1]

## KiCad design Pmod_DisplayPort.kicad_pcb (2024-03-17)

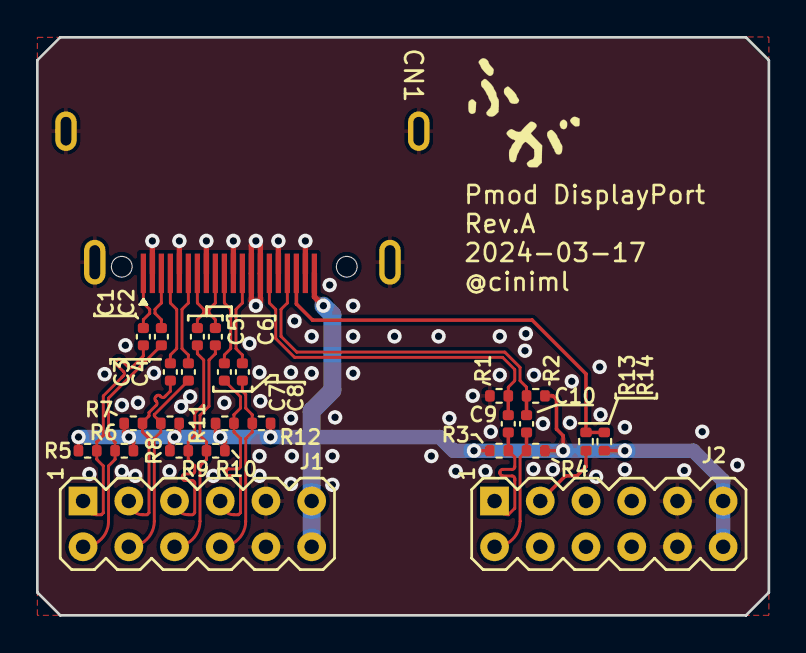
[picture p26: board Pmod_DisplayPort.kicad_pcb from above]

Board: 2 copper layers, 40.6 x 32.1 mm, 28 parts (0 on the bottom side), 24 nets.

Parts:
C1, C2, C3, C4, C5, C6, C7, C8, C9, C10: 100n; C_0402_1005Metric
CN1: DisplayPort_DP-GD-120PWB
J1, J2: Conn_02x06_Top_Bottom; Conn_Pmod_Spec_B_Thin
LOGO1: Logo_Open_Hardware_Small; logo
R1, R2, R13: 100k; R_0402_1005Metric
R3, R4, R5, R6, R7, R8, R9, R10, R11, R12: 50; R_0402_1005Metric
R14: 10k; R_0402_1005Metric

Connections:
+3V3: CN1.20 (DP_PWR), J1.6, J1.12, J2.6, J2.12, R2.1, R3.1, R4.1, R5.1, R6.1, R7.1, R8.1, R9.1, R10.1, R11.1, R12.1, R13.1
/AUX_N: C10.2, CN1.17 (AUX_CH_N), R2.2
/AUX_P: C9.2, CN1.15 (AUX_CH_P), R1.2
/HPD: CN1.18 (HOT_PLUG), R13.2, R14.1
/ML0_N: C2.2, CN1.3 (ML_LANE0_N)
/ML0_P: C1.2, CN1.1 (ML_LANE0_P)
/ML1_N: C4.2, CN1.6 (ML_LANE1_N)
/ML1_P: C3.2, CN1.4 (ML_LANE1_P)
/ML2_N: C6.2, CN1.9 (ML_LANE2_N)
/ML2_P: C5.2, CN1.7 (ML_LANE2_P)
/ML3_N: C8.2, CN1.12 (ML_LANE3_N)
/ML3_P: C7.2, CN1.10 (ML_LANE3_P)
/PMOD_AUX_CH_N: C10.1, J2.7, R4.2
/PMOD_AUX_CH_P: C9.1, J2.1, R3.2
/PMOD_L0_N: C2.1, J1.7, R6.2
/PMOD_L0_P: C1.1, J1.1, R5.2
/PMOD_L1_N: C4.1, J1.8, R8.2
/PMOD_L1_P: C3.1, J1.2, R7.2
/PMOD_L2_N: C6.1, J1.9, R10.2
/PMOD_L2_P: C5.1, J1.3, R9.2
/PMOD_L3_N: C8.1, J1.10, R12.2
/PMOD_L3_P: C7.1, J1.4, R11.2
/PMOD_P2_HOT_PLUG: J2.2, R14.2
GND: CN1.2 (GND), CN1.5 (GND), CN1.8 (GND), CN1.11 (GND), CN1.13 (CONFIG1), CN1.14 (CONFIG2), CN1.16 (GND), CN1.19 (Return), CN1.FG, J1.5, J1.11, J2.5, J2.11, R1.1

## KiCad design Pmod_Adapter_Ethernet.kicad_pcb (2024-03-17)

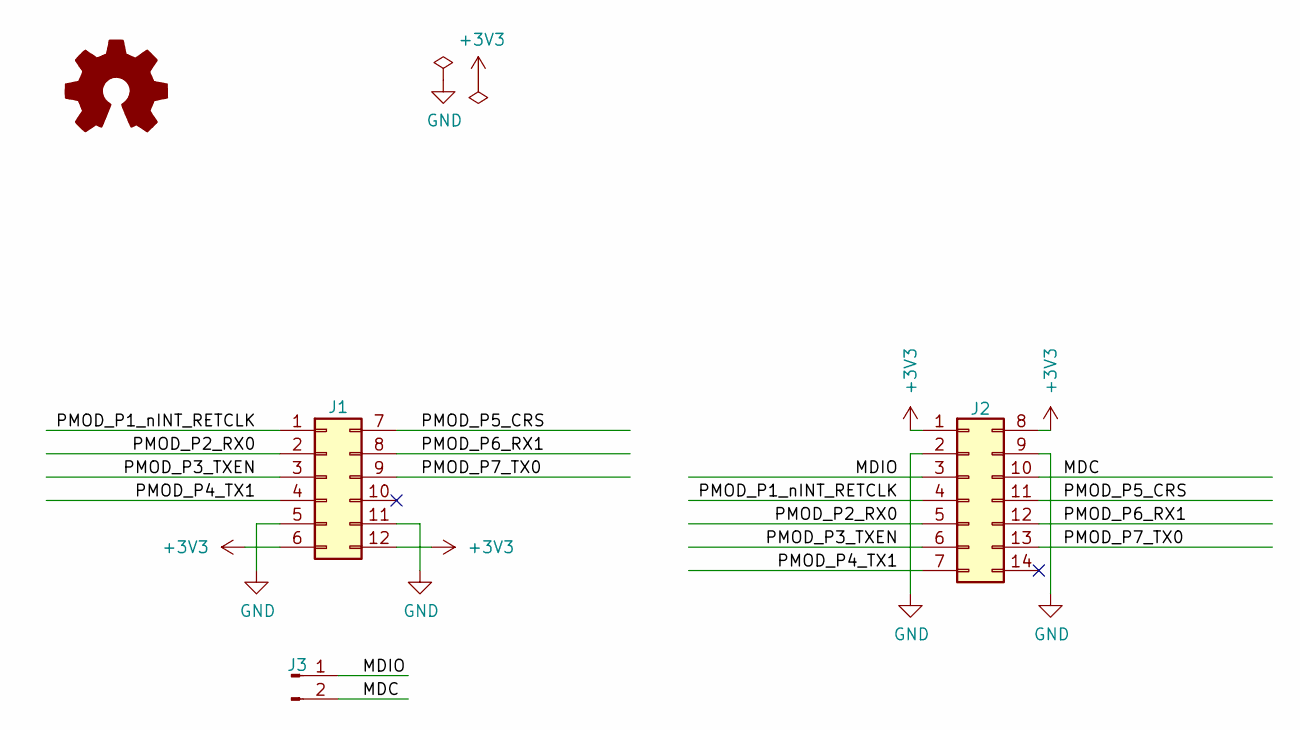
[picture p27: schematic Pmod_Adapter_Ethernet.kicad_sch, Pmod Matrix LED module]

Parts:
J1: Conn_02x06_Top_Bottom; Conn_Pmod_Spec_B_Thin
J2: Conn_02x07_Top_Bottom; Conn_WaveShare_Ethernet_Spec_D_Thin
J3: Conn_01x02_Pin; PinHeader_1x02_P2.54mm_Vertical
LOGO1: Logo_Open_Hardware_Small; logo

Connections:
+3V3: J1.6, J1.12, J2.1, J2.8
/MDC: J2.10, J3.2
/MDIO: J2.3, J3.1
/PMOD_P1_nINT_RETCLK: J1.1, J2.4
/PMOD_P2_RX0: J1.2, J2.5
/PMOD_P3_TXEN: J1.3, J2.6
/PMOD_P4_TX1: J1.4, J2.7
/PMOD_P5_CRS: J1.7, J2.11
/PMOD_P6_RX1: J1.8, J2.12
/PMOD_P7_TX0: J1.9, J2.13
GND: J1.5, J1.11, J2.2, J2.9

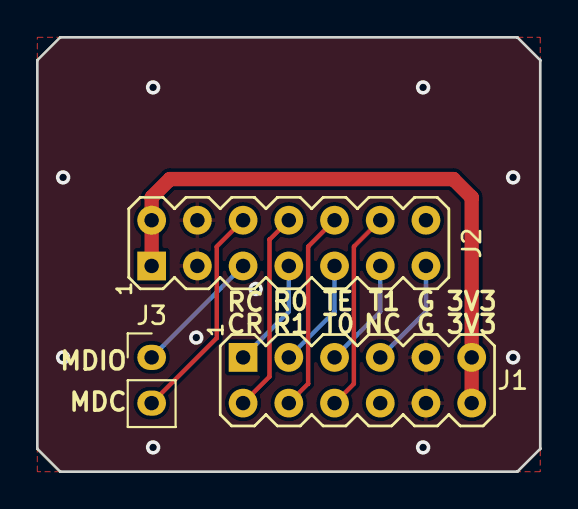
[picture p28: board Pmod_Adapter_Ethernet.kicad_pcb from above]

Board: 2 copper layers, 27.9 x 24.1 mm, 4 parts (1 on the bottom side), 11 nets.

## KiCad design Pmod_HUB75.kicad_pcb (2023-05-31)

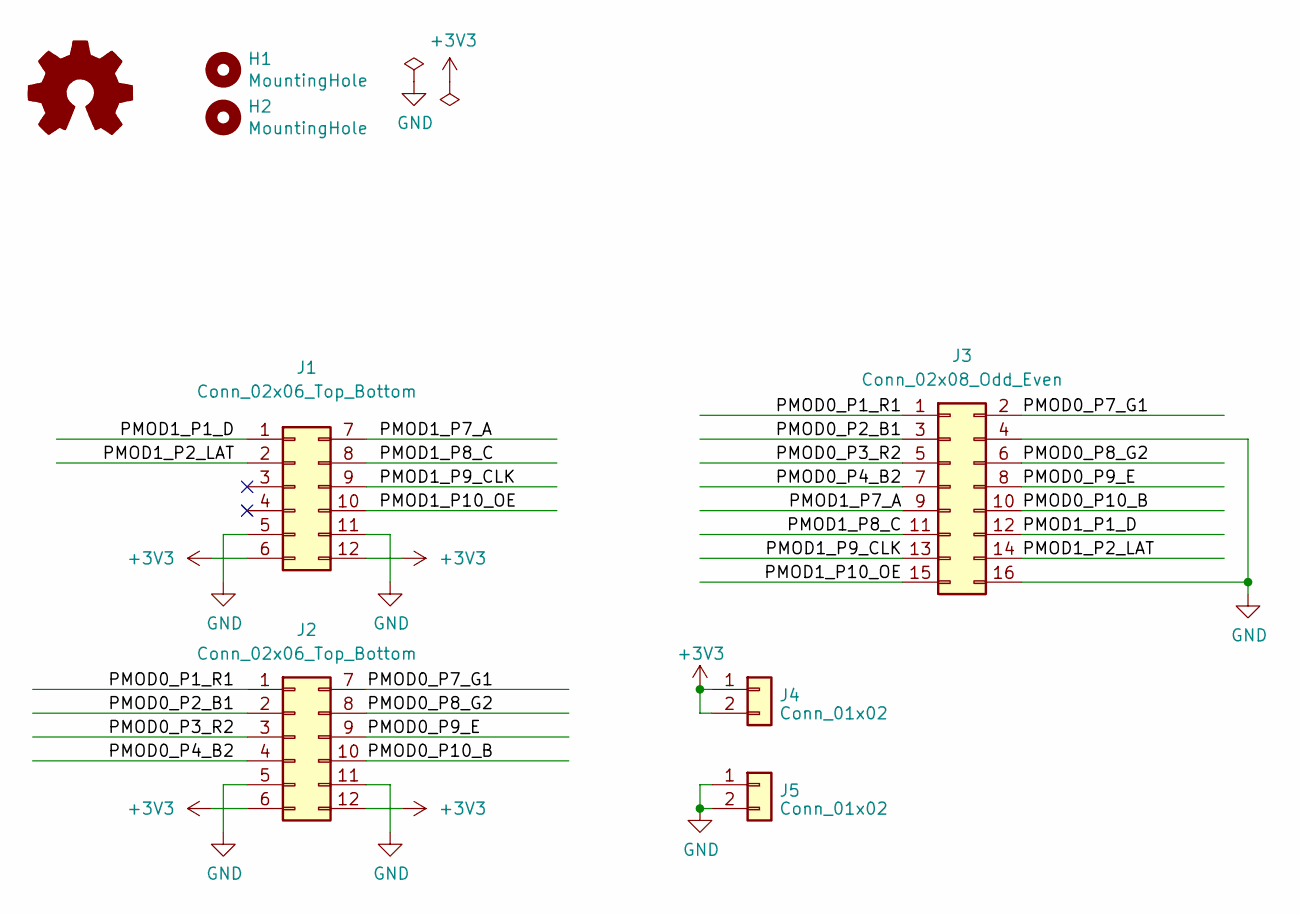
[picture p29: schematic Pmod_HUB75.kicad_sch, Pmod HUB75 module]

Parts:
H1, H2: MountingHole; MountingHole_3.2mm_M3_Mask
J1, J2: Conn_02x06_Top_Bottom; Conn_Pmod_Spec_B_Thin
J3: Conn_02x08_Odd_Even; PinHeader_2x08_P2.54mm_Vertical
J4, J5: Conn_01x02; PinHeader_1x02_P2.54mm_Vertical
LOGO1: Logo_Open_Hardware_Small; logo

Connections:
+3V3: J1.6, J1.12, J2.6, J2.12, J4.1, J4.2
/PMOD0_P1_R1: J2.1, J3.1
/PMOD0_P2_B1: J2.2, J3.3
/PMOD0_P3_R2: J2.3, J3.5
/PMOD0_P4_B2: J2.4, J3.7
/PMOD0_P7_G1: J2.7, J3.2
/PMOD0_P8_G2: J2.8, J3.6
/PMOD0_P9_E: J2.9, J3.8
/PMOD0_P10_B: J2.10, J3.10
/PMOD1_P1_D: J1.1, J3.12
/PMOD1_P2_LAT: J1.2, J3.14
/PMOD1_P7_A: J1.7, J3.9
/PMOD1_P8_C: J1.8, J3.11
/PMOD1_P9_CLK: J1.9, J3.13
/PMOD1_P10_OE: J1.10, J3.15
GND: J1.5, J1.11, J2.5, J2.11, J3.4, J3.16, J5.1, J5.2

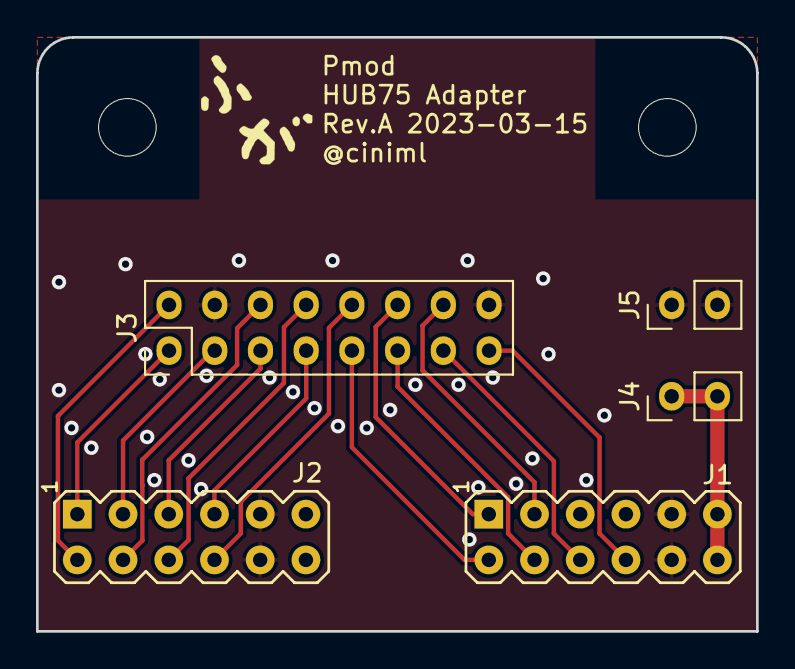
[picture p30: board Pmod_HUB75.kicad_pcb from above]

Board: 2 copper layers, 40.0 x 33.0 mm, 8 parts (0 on the bottom side), 16 nets.

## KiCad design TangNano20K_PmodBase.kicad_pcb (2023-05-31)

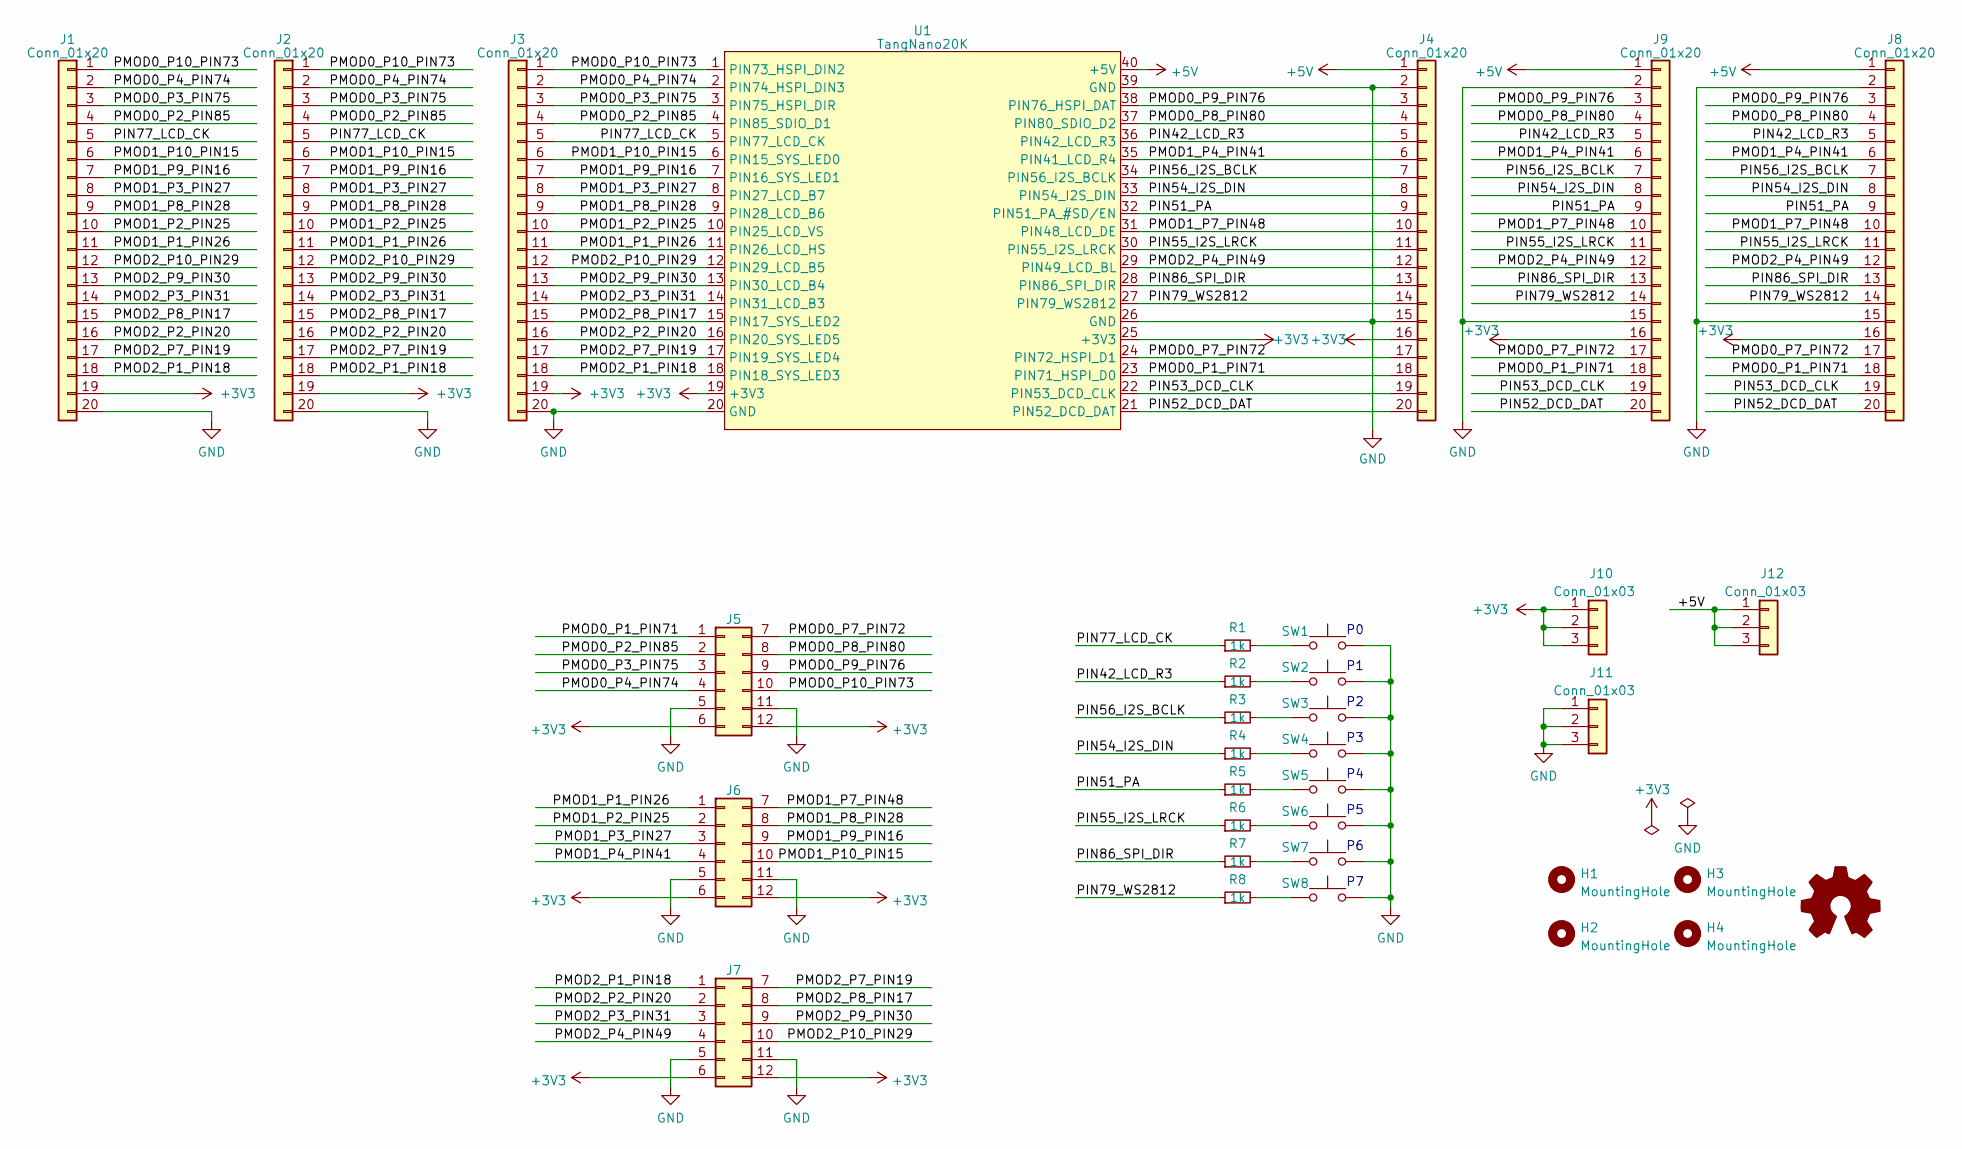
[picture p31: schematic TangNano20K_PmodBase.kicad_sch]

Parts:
H1, H2, H3, H4: MountingHole; MountingHole_3.2mm_M3_Mask
J1, J2, J3, J4, J8, J9: Conn_01x20; PinHeader_1x20_P2.54mm_Vertical
J5, J6, J7: Conn_02x06_Top_Bottom; Conn_Pmod_Spec_D_Thin
J10, J11, J12: Conn_01x03; PinHeader_1x03_P2.54mm_Vertical
LOGO1: Logo_Open_Hardware_Small; logo
R1, R2, R3, R4, R5, R6, R7, R8: 1k; R_Axial_DIN0204_L3.6mm_D1.6mm_P5.08mm_Horizontal_with_1608m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
SW1, SW2, SW3, SW4, SW5, SW6, SW7, SW8: SW_Push; TVBP06-BN043XX-B
U1: TangNano20K

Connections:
+3V3: J1.19, J2.19, J3.19, J4.16, J5.6, J5.12, J6.6, J6.12, J7.6, J7.12, J8.16, J9.16, J10.1, J10.2, J10.3, U1.19 (+3V3), U1.25 (+3V3)
+5V: J4.1, J8.1, J9.1, J12.1, J12.2, J12.3, U1.40 (+5V)
/PIN42_LCD_R3: J4.5, J8.5, J9.5, R2.1, U1.36 (PIN42_LCD_R3)
/PIN51_PA: J4.9, J8.9, J9.9, R5.1, U1.32 (PIN51_PA_#SD/EN)
/PIN52_DCD_DAT: J4.20, J8.20, J9.20, U1.21 (PIN52_DCD_DAT)
/PIN53_DCD_CLK: J4.19, J8.19, J9.19, U1.22 (PIN53_DCD_CLK)
/PIN54_I2S_DIN: J4.8, J8.8, J9.8, R4.1, U1.33 (PIN54_I2S_DIN)
/PIN55_I2S_LRCK: J4.11, J8.11, J9.11, R6.1, U1.30 (PIN55_I2S_LRCK)
/PIN56_I2S_BCLK: J4.7, J8.7, J9.7, R3.1, U1.34 (PIN56_I2S_BCLK)
/PIN77_LCD_CK: J1.5, J2.5, J3.5, R1.1, U1.5 (PIN77_LCD_CK)
/PIN79_WS2812: J4.14, J8.14, J9.14, R8.1, U1.27 (PIN79_WS2812)
/PIN86_SPI_DIR: J4.13, J8.13, J9.13, R7.1, U1.28 (PIN86_SPI_DIR)
/PMOD0_P1_PIN71: J4.18, J5.1, J8.18, J9.18, U1.23 (PIN71_HSPI_D0)
/PMOD0_P2_PIN85: J1.4, J2.4, J3.4, J5.2, U1.4 (PIN85_SDIO_D1)
/PMOD0_P3_PIN75: J1.3, J2.3, J3.3, J5.3, U1.3 (PIN75_HSPI_DIR)
/PMOD0_P4_PIN74: J1.2, J2.2, J3.2, J5.4, U1.2 (PIN74_HSPI_DIN3)
/PMOD0_P7_PIN72: J4.17, J5.7, J8.17, J9.17, U1.24 (PIN72_HSPI_D1)
/PMOD0_P8_PIN80: J4.4, J5.8, J8.4, J9.4, U1.37 (PIN80_SDIO_D2)
/PMOD0_P9_PIN76: J4.3, J5.9, J8.3, J9.3, U1.38 (PIN76_HSPI_DAT)
/PMOD0_P10_PIN73: J1.1, J2.1, J3.1, J5.10, U1.1 (PIN73_HSPI_DIN2)
/PMOD1_P1_PIN26: J1.11, J2.11, J3.11, J6.1, U1.11 (PIN26_LCD_HS)
/PMOD1_P2_PIN25: J1.10, J2.10, J3.10, J6.2, U1.10 (PIN25_LCD_VS)
/PMOD1_P3_PIN27: J1.8, J2.8, J3.8, J6.3, U1.8 (PIN27_LCD_B7)
/PMOD1_P4_PIN41: J4.6, J6.4, J8.6, J9.6, U1.35 (PIN41_LCD_R4)
/PMOD1_P7_PIN48: J4.10, J6.7, J8.10, J9.10, U1.31 (PIN48_LCD_DE)
/PMOD1_P8_PIN28: J1.9, J2.9, J3.9, J6.8, U1.9 (PIN28_LCD_B6)
/PMOD1_P9_PIN16: J1.7, J2.7, J3.7, J6.9, U1.7 (PIN16_SYS_LED1)
/PMOD1_P10_PIN15: J1.6, J2.6, J3.6, J6.10, U1.6 (PIN15_SYS_LED0)
/PMOD2_P1_PIN18: J1.18, J2.18, J3.18, J7.1, U1.18 (PIN18_SYS_LED3)
/PMOD2_P2_PIN20: J1.16, J2.16, J3.16, J7.2, U1.16 (PIN20_SYS_LED5)
/PMOD2_P3_PIN31: J1.14, J2.14, J3.14, J7.3, U1.14 (PIN31_LCD_B3)
/PMOD2_P4_PIN49: J4.12, J7.4, J8.12, J9.12, U1.29 (PIN49_LCD_BL)
/PMOD2_P7_PIN19: J1.17, J2.17, J3.17, J7.7, U1.17 (PIN19_SYS_LED4)
/PMOD2_P8_PIN17: J1.15, J2.15, J3.15, J7.8, U1.15 (PIN17_SYS_LED2)
/PMOD2_P9_PIN30: J1.13, J2.13, J3.13, J7.9, U1.13 (PIN30_LCD_B4)
/PMOD2_P10_PIN29: J1.12, J2.12, J3.12, J7.10, U1.12 (PIN29_LCD_B5)
GND: J1.20, J2.20, J3.20, J4.2, J4.15, J5.5, J5.11, J6.5, J6.11, J7.5, J7.11, J8.2, J8.15, J9.2, J9.15, J11.1, J11.2, J11.3, SW1.2, SW2.2, SW3.2, SW4.2, SW5.2, SW6.2, SW7.2, SW8.2, U1.20 (GND), U1.26 (GND), U1.39 (GND)
unnamed: R1.2, SW1.1
unnamed: R2.2, SW2.1
unnamed: R3.2, SW3.1
unnamed: R4.2, SW4.1
unnamed: R5.2, SW5.1
unnamed: R6.2, SW6.1
unnamed: R7.2, SW7.1
unnamed: R8.2, SW8.1

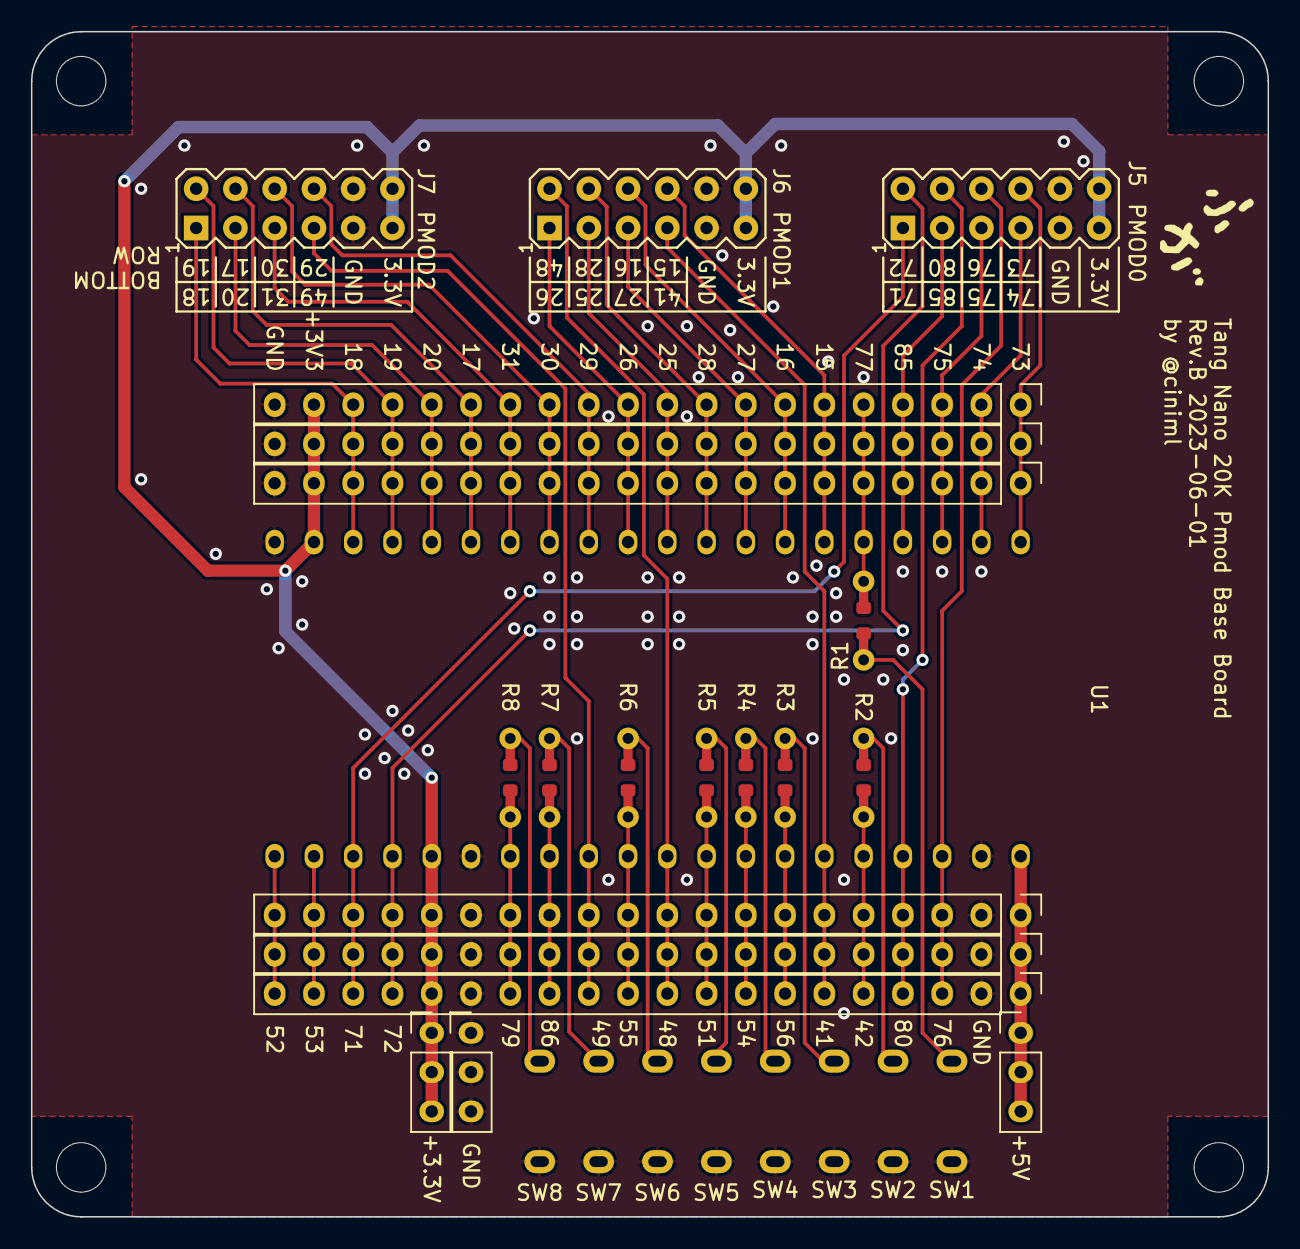
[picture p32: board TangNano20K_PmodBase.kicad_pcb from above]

Board: 2 copper layers, 80.0 x 76.7 mm, 34 parts (0 on the bottom side), 45 nets.

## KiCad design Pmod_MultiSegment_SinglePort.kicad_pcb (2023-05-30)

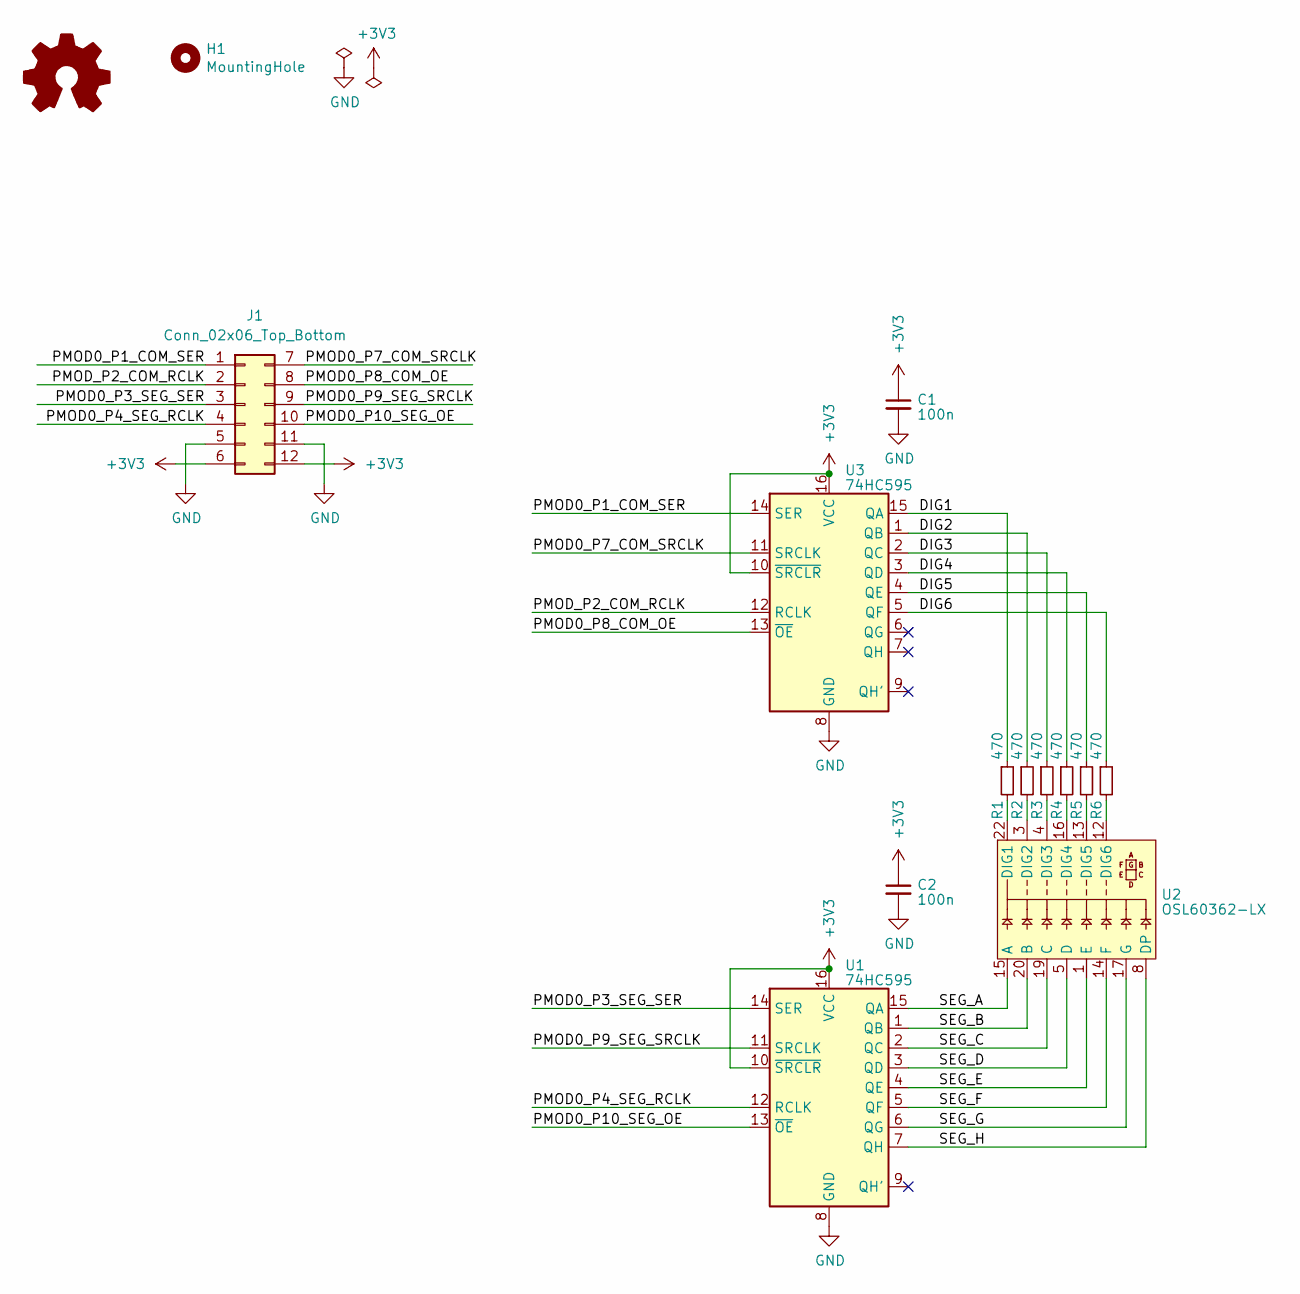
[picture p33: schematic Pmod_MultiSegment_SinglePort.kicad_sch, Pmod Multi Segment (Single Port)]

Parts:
C1, C2: 100n; C_0603_1608Metric
H1: MountingHole; MountingHole_3.2mm_M3_Mask
J1: Conn_02x06_Top_Bottom; Conn_Pmod_Spec_B_Thin
LOGO1: Logo_Open_Hardware_Small; logo
R1, R2, R3, R4, R5, R6: 470; R_Axial_DIN0204_L3.6mm_D1.6mm_P5.08mm_Horizontal_with_1608m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
U1, U3: 74HC595; SOIC-16W_5.3x10.2mm_P1.27mm
U2: OSL60362-LX; OSL60362

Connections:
+3V3: C1.1, C2.1, J1.6, J1.12, U1.10 (~SRCLR), U1.16 (VCC), U3.10 (~SRCLR), U3.16 (VCC)
/DIG1: R1.1, U3.15 (QA)
/DIG2: R2.1, U3.1 (QB)
/DIG3: R3.1, U3.2 (QC)
/DIG4: R4.1, U3.3 (QD)
/DIG5: R5.1, U3.4 (QE)
/DIG6: R6.1, U3.5 (QF)
/PMOD0_P1_COM_SER: J1.1, U3.14 (SER)
/PMOD0_P3_SEG_SER: J1.3, U1.14 (SER)
/PMOD0_P4_SEG_RCLK: J1.4, U1.12 (RCLK)
/PMOD0_P7_COM_SRCLK: J1.7, U3.11 (SRCLK)
/PMOD0_P8_COM_OE: J1.8, U3.13 (~OE)
/PMOD0_P9_SEG_SRCLK: J1.9, U1.11 (SRCLK)
/PMOD0_P10_SEG_OE: J1.10, U1.13 (~OE)
/PMOD_P2_COM_RCLK: J1.2, U3.12 (RCLK)
/SEG_A: U1.15 (QA), U2.15 (A)
/SEG_B: U1.1 (QB), U2.20 (B)
/SEG_C: U1.2 (QC), U2.19 (C)
/SEG_D: U1.3 (QD), U2.5 (D)
/SEG_E: U1.4 (QE), U2.1 (E)
/SEG_F: U1.5 (QF), U2.14 (F)
/SEG_G: U1.6 (QG), U2.17 (G)
/SEG_H: U1.7 (QH), U2.8 (DP)
GND: C1.2, C2.2, J1.5, J1.11, U1.8 (GND), U3.8 (GND)
unnamed: R1.2, U2.22 (DIG1)
unnamed: R2.2, U2.3 (DIG2)
unnamed: R3.2, U2.4 (DIG3)
unnamed: R4.2, U2.16 (DIG4)
unnamed: R5.2, U2.13 (DIG5)
unnamed: R6.2, U2.12 (DIG6)

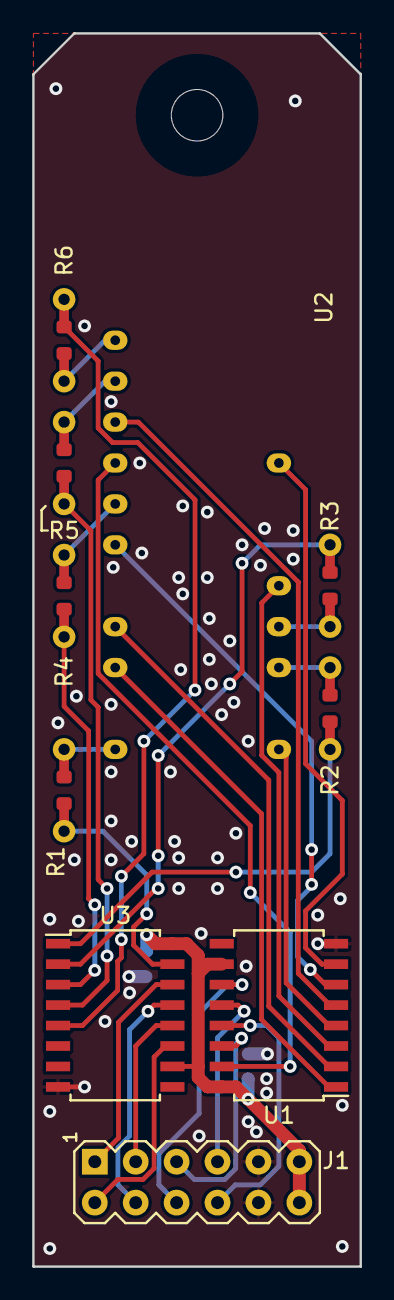
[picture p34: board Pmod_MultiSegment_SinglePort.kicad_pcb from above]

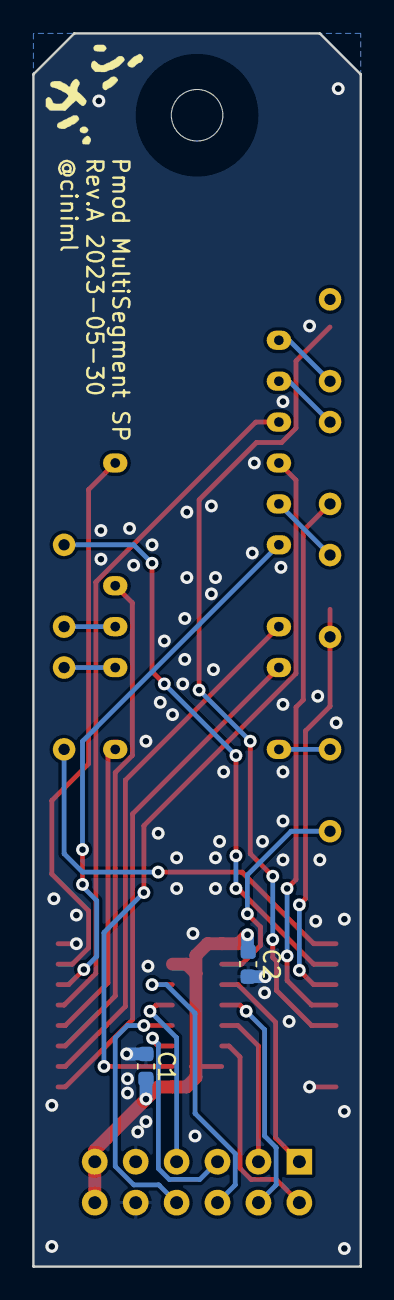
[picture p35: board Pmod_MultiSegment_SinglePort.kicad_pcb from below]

Board: 2 copper layers, 20.3 x 76.6 mm, 14 parts (3 on the bottom side), 30 nets.

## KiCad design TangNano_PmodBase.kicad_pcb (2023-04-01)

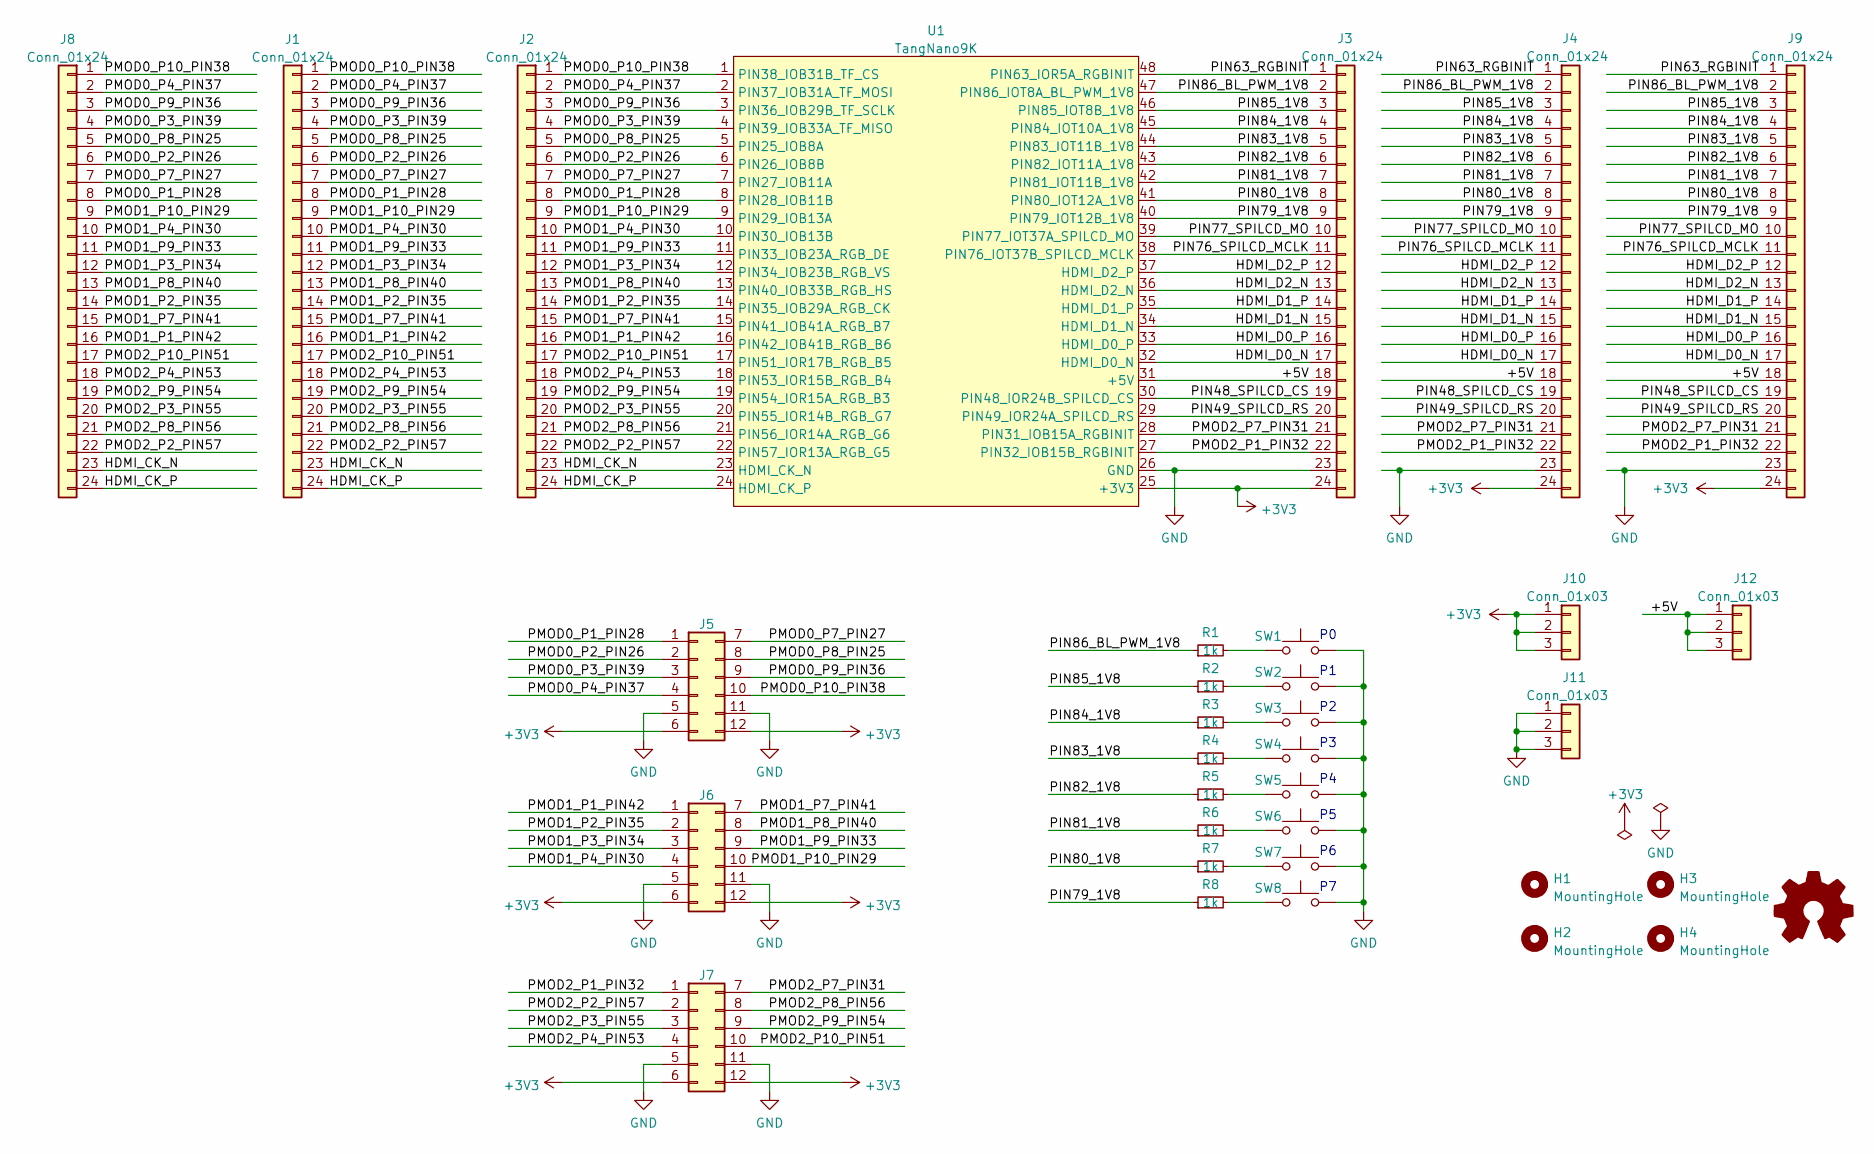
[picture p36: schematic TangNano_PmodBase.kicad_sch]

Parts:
H1, H2, H3, H4: MountingHole; MountingHole_3.2mm_M3_Mask
J1, J2, J3, J4, J8, J9: Conn_01x24; PinHeader_1x24_P2.54mm_Vertical
J5, J6, J7: Conn_02x06_Top_Bottom; Conn_Pmod_Spec_D_Thin
J10, J11, J12: Conn_01x03; PinHeader_1x03_P2.54mm_Vertical
LOGO1: Logo_Open_Hardware_Small; logo
R1, R2, R3, R4, R5, R6, R7, R8: 1k; R_Axial_DIN0204_L3.6mm_D1.6mm_P5.08mm_Horizontal_with_1608m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
SW1, SW2, SW3, SW4, SW5, SW6, SW7, SW8: SW_Push; TVBP06-BN043XX-B
U1: TangNano9K

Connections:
+3V3: J3.24, J4.24, J5.6, J5.12, J6.6, J6.12, J7.6, J7.12, J9.24, J10.1, J10.2, J10.3, U1.25 (+3V3)
/+5V: J3.18, J4.18, J9.18, J12.1, J12.2, J12.3, U1.31 (+5V)
/HDMI_CK_N: J1.23, J2.23, J8.23, U1.23 (HDMI_CK_N)
/HDMI_CK_P: J1.24, J2.24, J8.24, U1.24 (HDMI_CK_P)
/HDMI_D0_N: J3.17, J4.17, J9.17, U1.32 (HDMI_D0_N)
/HDMI_D0_P: J3.16, J4.16, J9.16, U1.33 (HDMI_D0_P)
/HDMI_D1_N: J3.15, J4.15, J9.15, U1.34 (HDMI_D1_N)
/HDMI_D1_P: J3.14, J4.14, J9.14, U1.35 (HDMI_D1_P)
/HDMI_D2_N: J3.13, J4.13, J9.13, U1.36 (HDMI_D2_N)
/HDMI_D2_P: J3.12, J4.12, J9.12, U1.37 (HDMI_D2_P)
/PIN48_SPILCD_CS: J3.19, J4.19, J9.19, U1.30 (PIN48_IOR24B_SPILCD_CS)
/PIN49_SPILCD_RS: J3.20, J4.20, J9.20, U1.29 (PIN49_IOR24A_SPILCD_RS)
/PIN63_RGBINIT: J3.1, J4.1, J9.1, U1.48 (PIN63_IOR5A_RGBINIT)
/PIN76_SPILCD_MCLK: J3.11, J4.11, J9.11, U1.38 (PIN76_IOT37B_SPILCD_MCLK)
/PIN77_SPILCD_MO: J3.10, J4.10, J9.10, U1.39 (PIN77_IOT37A_SPILCD_MO)
/PIN79_1V8: J3.9, J4.9, J9.9, R8.1, U1.40 (PIN79_IOT12B_1V8)
/PIN80_1V8: J3.8, J4.8, J9.8, R7.1, U1.41 (PIN80_IOT12A_1V8)
/PIN81_1V8: J3.7, J4.7, J9.7, R6.1, U1.42 (PIN81_IOT11B_1V8)
/PIN82_1V8: J3.6, J4.6, J9.6, R5.1, U1.43 (PIN82_IOT11A_1V8)
/PIN83_1V8: J3.5, J4.5, J9.5, R4.1, U1.44 (PIN83_IOT11B_1V8)
/PIN84_1V8: J3.4, J4.4, J9.4, R3.1, U1.45 (PIN84_IOT10A_1V8)
/PIN85_1V8: J3.3, J4.3, J9.3, R2.1, U1.46 (PIN85_IOT8B_1V8)
/PIN86_BL_PWM_1V8: J3.2, J4.2, J9.2, R1.1, U1.47 (PIN86_IOT8A_BL_PWM_1V8)
/PMOD0_P1_PIN28: J1.8, J2.8, J5.1, J8.8, U1.8 (PIN28_IOB11B)
/PMOD0_P2_PIN26: J1.6, J2.6, J5.2, J8.6, U1.6 (PIN26_IOB8B)
/PMOD0_P3_PIN39: J1.4, J2.4, J5.3, J8.4, U1.4 (PIN39_IOB33A_TF_MISO)
/PMOD0_P4_PIN37: J1.2, J2.2, J5.4, J8.2, U1.2 (PIN37_IOB31A_TF_MOSI)
/PMOD0_P7_PIN27: J1.7, J2.7, J5.7, J8.7, U1.7 (PIN27_IOB11A)
/PMOD0_P8_PIN25: J1.5, J2.5, J5.8, J8.5, U1.5 (PIN25_IOB8A)
/PMOD0_P9_PIN36: J1.3, J2.3, J5.9, J8.3, U1.3 (PIN36_IOB29B_TF_SCLK)
/PMOD0_P10_PIN38: J1.1, J2.1, J5.10, J8.1, U1.1 (PIN38_IOB31B_TF_CS)
/PMOD1_P1_PIN42: J1.16, J2.16, J6.1, J8.16, U1.16 (PIN42_IOB41B_RGB_B6)
/PMOD1_P2_PIN35: J1.14, J2.14, J6.2, J8.14, U1.14 (PIN35_IOB29A_RGB_CK)
/PMOD1_P3_PIN34: J1.12, J2.12, J6.3, J8.12, U1.12 (PIN34_IOB23B_RGB_VS)
/PMOD1_P4_PIN30: J1.10, J2.10, J6.4, J8.10, U1.10 (PIN30_IOB13B)
/PMOD1_P7_PIN41: J1.15, J2.15, J6.7, J8.15, U1.15 (PIN41_IOB41A_RGB_B7)
/PMOD1_P8_PIN40: J1.13, J2.13, J6.8, J8.13, U1.13 (PIN40_IOB33B_RGB_HS)
/PMOD1_P9_PIN33: J1.11, J2.11, J6.9, J8.11, U1.11 (PIN33_IOB23A_RGB_DE)
/PMOD1_P10_PIN29: J1.9, J2.9, J6.10, J8.9, U1.9 (PIN29_IOB13A)
/PMOD2_P1_PIN32: J3.22, J4.22, J7.1, J9.22, U1.27 (PIN32_IOB15B_RGBINIT)
/PMOD2_P2_PIN57: J1.22, J2.22, J7.2, J8.22, U1.22 (PIN57_IOR13A_RGB_G5)
/PMOD2_P3_PIN55: J1.20, J2.20, J7.3, J8.20, U1.20 (PIN55_IOR14B_RGB_G7)
/PMOD2_P4_PIN53: J1.18, J2.18, J7.4, J8.18, U1.18 (PIN53_IOR15B_RGB_B4)
/PMOD2_P7_PIN31: J3.21, J4.21, J7.7, J9.21, U1.28 (PIN31_IOB15A_RGBINIT)
/PMOD2_P8_PIN56: J1.21, J2.21, J7.8, J8.21, U1.21 (PIN56_IOR14A_RGB_G6)
/PMOD2_P9_PIN54: J1.19, J2.19, J7.9, J8.19, U1.19 (PIN54_IOR15A_RGB_B3)
/PMOD2_P10_PIN51: J1.17, J2.17, J7.10, J8.17, U1.17 (PIN51_IOR17B_RGB_B5)
GND: J3.23, J4.23, J5.5, J5.11, J6.5, J6.11, J7.5, J7.11, J9.23, J11.1, J11.2, J11.3, SW1.2, SW2.2, SW3.2, SW4.2, SW5.2, SW6.2, SW7.2, SW8.2, U1.26 (GND)
unnamed: R1.2, SW1.1
unnamed: R2.2, SW2.1
unnamed: R3.2, SW3.1
unnamed: R4.2, SW4.1
unnamed: R5.2, SW5.1
unnamed: R6.2, SW6.1
unnamed: R7.2, SW7.1
unnamed: R8.2, SW8.1

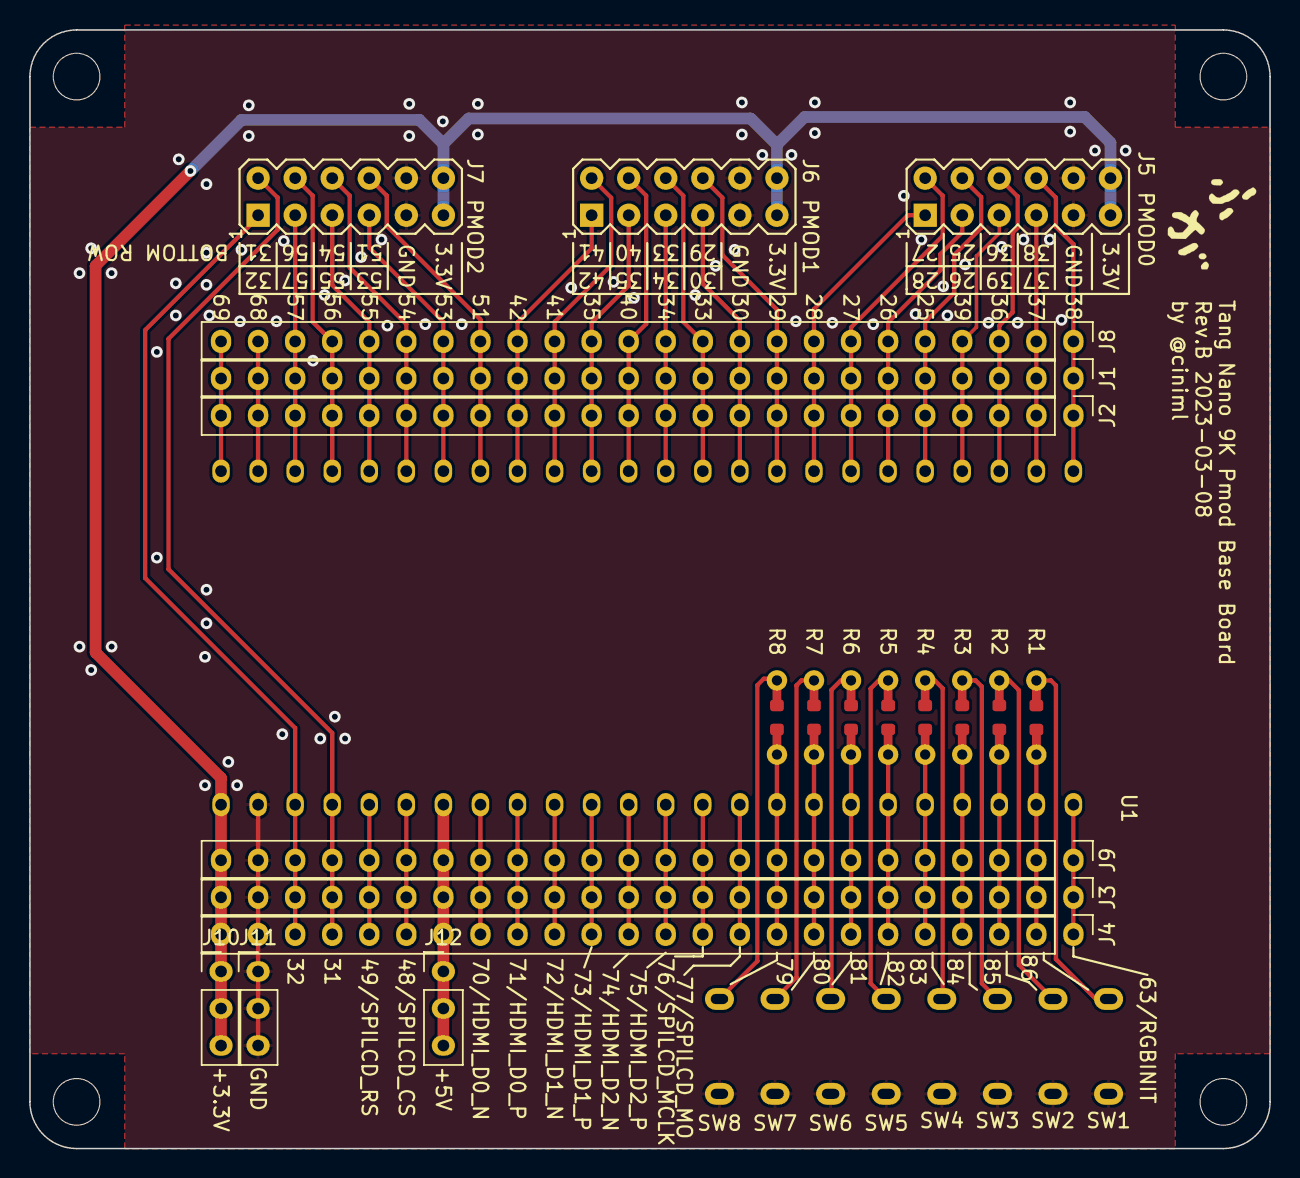
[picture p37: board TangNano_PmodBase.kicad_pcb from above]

Board: 2 copper layers, 85.0 x 76.7 mm, 34 parts (0 on the bottom side), 56 nets.

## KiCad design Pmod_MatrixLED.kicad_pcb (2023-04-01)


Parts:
H1, H2: MountingHole; MountingHole_3.2mm_M3_Mask
J1, J2: Conn_02x06_Top_Bottom; Conn_Pmod_Spec_B_Thin
LOGO1: Logo_Open_Hardware_Small; logo
R1, R2, R3, R4, R5, R6, R7, R8: 470; R_Axial_DIN0204_L3.6mm_D1.6mm_P5.08mm_Horizontal_with_1608m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
U1: OSL641501-AX

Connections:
+3V3: J1.6, J1.12, J2.6, J2.12
/PMOD0_P1_CATHODE1: J1.1, U1.14 (ROW2)
/PMOD0_P2_CATHODE3: J1.2, U1.12 (ROW4)
/PMOD0_P3_CATHODE5: J1.3, U1.7 (ROW6)
/PMOD0_P4_CATHODE7: J1.4, U1.5 (ROW8)
/PMOD0_P7_CATHODE0: J1.7, U1.9 (ROW1)
/PMOD0_P8_CATHODE2: J1.8, U1.8 (ROW3)
/PMOD0_P9_CATHODE4: J1.9, U1.1 (ROW5)
/PMOD0_P10_CATHODE6: J1.10, U1.2 (ROW7)
/PMOD1_P1_ANODE1: J2.1, R2.1
/PMOD1_P2_ANODE3: J2.2, R4.1
/PMOD1_P3_ANODE5: J2.3, R6.1
/PMOD1_P4_ANODE7: J2.4, R8.1
/PMOD1_P7_ANODE0: J2.7, R1.1
/PMOD1_P8_ANODE2: J2.8, R3.1
/PMOD1_P9_ANODE4: J2.9, R5.1
/PMOD1_P10_ANODE6: J2.10, R7.1
GND: J1.5, J1.11, J2.5, J2.11
unnamed: R1.2, U1.13 (COL1)
unnamed: R2.2, U1.3 (COL2)
unnamed: R3.2, U1.4 (COL3)
unnamed: R4.2, U1.10 (COL4)
unnamed: R5.2, U1.6 (COL5)
unnamed: R6.2, U1.11 (COL6)
unnamed: R7.2, U1.15 (COL7)
unnamed: R8.2, U1.16 (COL8)

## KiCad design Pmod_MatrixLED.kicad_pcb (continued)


Board: 2 copper layers, 40.0 x 70.0 mm, 14 parts (0 on the bottom side), 26 nets.

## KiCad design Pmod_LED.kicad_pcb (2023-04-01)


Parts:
D1, D2, D3, D4, D5, D6, D7, D8: RED; LED_D3.0mm
J1: Conn_02x06_Top_Bottom; Conn_Pmod_Spec_B_Thin
J2: Conn_02x06_Top_Bottom; Conn_Pmod_Spec_D_Thin
LOGO1: Logo_Open_Hardware_Small; logo

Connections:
+3V3: J1.6, J1.12, J2.6, J2.12
/PMOD_P1: D1.2 (A), J1.1, J2.1
/PMOD_P2: D2.2 (A), J1.2, J2.2
/PMOD_P3: D3.2 (A), J1.3, J2.3
/PMOD_P4: D4.2 (A), J1.4, J2.4
/PMOD_P7: D5.2 (A), J1.7, J2.7
/PMOD_P8: D6.2 (A), J1.8, J2.8
/PMOD_P9: D7.2 (A), J1.9, J2.9
/PMOD_P10: D8.2 (A), J1.10, J2.10
GND: D1.1 (K), D2.1 (K), D3.1 (K), D4.1 (K), D5.1 (K), D6.1 (K), D7.1 (K), D8.1 (K), J1.5, J1.11, J2.5, J2.11


Board: 2 copper layers, 17.8 x 34.6 mm, 11 parts (1 on the bottom side), 10 nets.

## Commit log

2023-04-02 Add schematic. Add TangPrimer20K extender doc.
    [Pmod_MatrixLED.kicad_sch, TangPrimer_PmodExtender.kicad_sch]
2023-05-30 Add Pmod Multi Segment (Single Port) board design
    [Pmod_MultiSegment_SinglePort.gbl, Pmod_MultiSegment_SinglePort.gbo, Pmod_MultiSegment_SinglePort.gbp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]
2023-05-31 Add TangNano20K PmodBase description and update to Rev.B
    [Pmod_HUB75.kicad_pcb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]
2024-03-17 ADd Pmod Ethernet Adapter
    [Pmod_Adapter_Ethernet.gbl, Pmod_Adapter_Ethernet.gbo, Pmod_Adapter_Ethernet.gbp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]
2024-03-17 Add Pmod DisplayPort
    [Pmod_DisplayPort.gbl, Pmod_DisplayPort.gbo, Pmod_DisplayPort.gbp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]
2024-03-17 Add assembly file
    [Pmod_DisplayPort.csv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]
2024-03-17 Change DisplayPort receptacle to HOAUC HYC16-DP20-178
    [Pmod_DisplayPort.csv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]
2024-07-31 Add akiduki list for Tang Nano 9K board

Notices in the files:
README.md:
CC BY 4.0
